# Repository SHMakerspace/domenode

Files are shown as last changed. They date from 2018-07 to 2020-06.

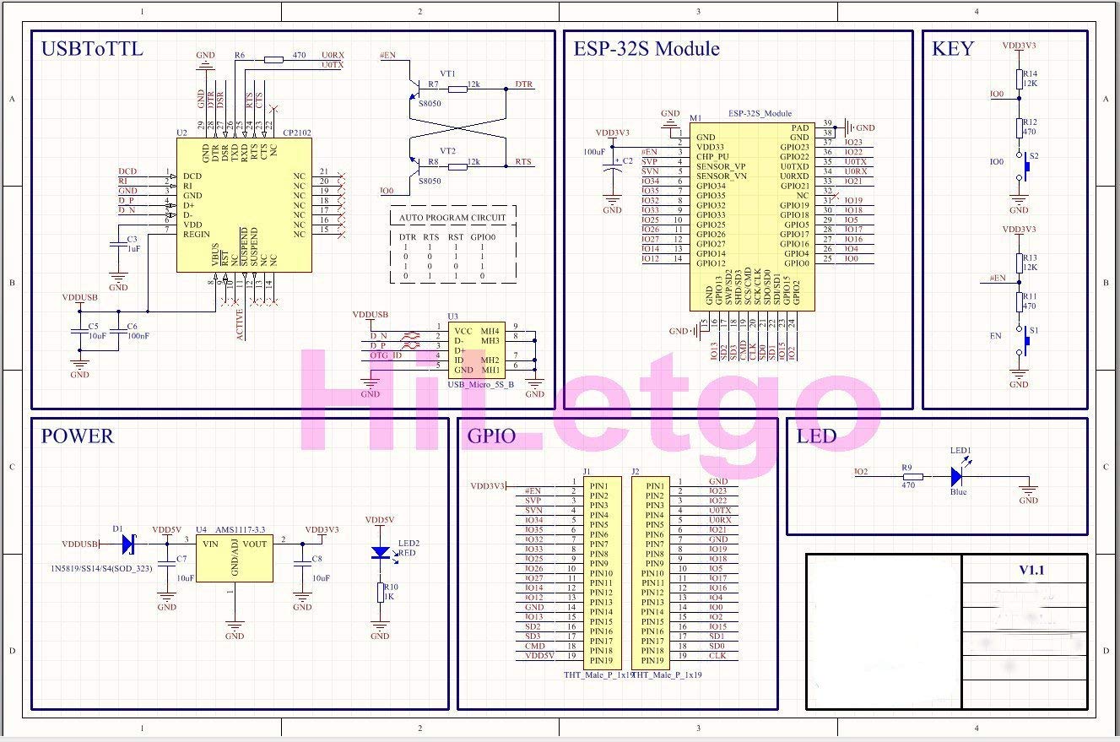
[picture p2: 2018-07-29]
Hardware/Nodes/datasheets/devboard_schematic.jpg

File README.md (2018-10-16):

# domenode
A CAN bus controlled, WiFi enabled network of dome node LEDs with many features

# Features
* :heavy_check_mark: ESP32 microcontroller (WiFi, bluetooth)
  * Pads for both ESP32 standalone module and dev board variants
  * OTA wireless firmware updates
* :heavy_check_mark: SN65HVD230 CAN bus transceiver
* :heavy_check_mark: 2x RJ45 connectors for CAN in and passthrough
* :heavy_check_mark: 5x WS2812/NeoPixel for RGB lighting
* :heavy_check_mark: On-board buck regulator
* :heavy_check_mark: 2x push switches
* :heavy_check_mark: Power and GPIO LED
* :heavy_check_mark: many headers for sensors and attachments (I2C, GPIOs, power etc)
* :red_circle: A shield header for expansion boards (to be added)

# Sensors (all optional and do not need to be populated)
Optional features by means of populating those pads are:
* :question: Outer and inner facing LDRs for ambient/transmitted light sensing
* :question: 2x tactile push switches for on-board input
* :question: Heavier duty power RGB LED shield connector (exposes 24V and R,G,B GPIOs)
* :question: IR Tx/Rx and (hopefully!) a ghetto distance sensor
* :question: Speaker
* :question: Capacitive touch
* :question: Microphone - MAX4466 based breakout board connector (footprints could be added to board, alternative idea is I2S)

# Firmware notes
* CAN bus - http://www.barth-dev.de/can-driver-esp32/
* NeoPixels - https://www.instructables.com/id/ESP32-Bluetooth-Ambience-Light-Controller-With-WS2/
* Microphone -https://www.hackster.io/julianfschroeter/esp32-voice-streamer-52bd7e , https://github.com/MrBuddyCasino/ESP32_Alexa
* Speaker - http://www.xtronical.com/basics/audio/dacs-on-esp32/
* IR sensor - https://github.com/mdhiggins/ESP8266-HTTP-IR-Blaster
* I2C bus - https://randomnerdtutorials.com/esp32-with-bmp180-barometric-sensor/

# BoM and Components

## 1. Basic functionality and programming
* 1x ESP32 module
* 1x SOT-223 3v3 LDO regulator
* 2x 0603 10uF ceramic capacitors (decoupling)
* 2x 100uF tantalum capacitors (decoupling)
* 1x 4 pin ISP header
* 1x 2 pin SW0 flashing header
* 2x 0805 LED (power and blink)
* 2x 0603 resistors for LEDs (470 and 1k)
* 1x 0603 10k resistor EN (very much needed, R10)

## 2. NeoPixels
* 9x WS2812 LEDs
* 1x 0603 470 ohm resistor (R13)
* 9x 0603 100nF ceramic capacitors

## 3. External Power
* 1x MINI-360 buck regulator module (U1)
* 1x 1N5819 protection diode
* 1x 1210 10uF >24v capacitor (C1)
* 2x 0603 10uF ceramic capacitors (C2, C4 decoupling)
* 2x RJ45 connectors

## 4. CAN Bus
* 1x SN65HVD230DR transceiver IC (U6)
* 1x 2 pin CANTERM header
* 1x 0603 120 ohm resistor (R16)
* 1x 0603 10k resistor (R17)
* 1x 0603 100nF capacitor (C14, decoupling)

# Serial Programming
Order is:
Black, Green, White, Red 
(GND), (Rx), (Tx), (5V)

#Flashing Procedure
* 1. Determine COM port with command `mode`
* 2. Open terminal in esp32 python environment
* 3. esptool --chip esp32 -p COM<x> write_flash -z 0x1000 <firmware_bin>

Uploading files

ampy -p COM<x> put <file>

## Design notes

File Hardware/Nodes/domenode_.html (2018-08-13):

## KiBoM PCB Bill of Materials

Source File | D:\P_Projects\domenode\Hardware\Nodes\domenode.sch
BoM Date | 10/08/2018 20:48:50
Schematic Version
Schematic Date
KiCad Version | Eeschema (5.0.0)
Component Groups | 48
Component Count (per PCB) | 80
Fitted Components (per PCB) | 80
Number of PCBs | 1
Total Component Count (for 1 PCBs) | 80

## Component Groups

KiCad Fields (default)

Generated Fields

User Fields

Empty Fields

| Description | Part | References | Value | Footprint | Quantity Per PCB | Datasheet
1 | Unpolarized capacitor | C | C6 C7 C8 C9 C10 C11 C12 C13 C14 C15 | 100nF | C_0603_1608Metric_Pad1.05x0.95mm_HandSolder | 10 | ~
2 | Polarised capacitor | CP | C3 C17 | 100uF | CP_EIA-3528-21_Kemet-B_Pad1.50x2.35mm_HandSolder | 2 | 100uF tantalum cap
3 | Unpolarized capacitor | C | C1 | 10uF | C_1210_3225Metric_Pad1.42x2.65mm_HandSolder | 1 | http://cpc.farnell.com/multicomp/mcca000585/mlcc-1210-y5v-25v-10uf/dp/CA06791?st=10uF%20capacitor
4 | Unpolarized capacitor | C | C2 C4 C5 C16 | 10uF | C_0603_1608Metric_Pad1.05x0.95mm_HandSolder | 4 | ~
5 | Zener Diode | D_Zener | D10 | 1N5819 | D_DO-41_SOD81_P7.62mm_Horizontal | 1 | ~
6 | LED generic | LED | D12 | BLINK | LED_0805_2012Metric_Pad1.15x1.40mm_HandSolder | 1 | ~
7 | Infrared LED , 3mm LED package | IR204A | D13 | IRLED | LED_D3.0mm_IRBlack | 1 | http://www.everlight.com/file/ProductFile/IR204-A.pdf
8 | LED generic | LED | D11 | POWER | LED_0805_2012Metric_Pad1.15x1.40mm_HandSolder | 1 | ~
9 | RGB LED with integrated controller | WS2812B | D1 D2 D3 D4 D5 D6 D7 D8 D9 | WS2812B | LED_WS2812B_PLCC4_5.0x5.0mm_P3.2mm | 9 | https://cdn-shop.adafruit.com/datasheets/WS2812B.pdf
10 | Generic connector, double row, 02x03, odd/even pin numbering scheme (row 1 odd numbers, row 2 even numbers), script generated (kicad-library-utils/schlib/autogen/connector/) | Conn_02x03_Odd_Even | J12 | 24V | PinHeader_2x03_P2.54mm_Vertical | 1 | ~
11 | Generic connector, double row, 02x03, odd/even pin numbering scheme (row 1 odd numbers, row 2 even numbers), script generated (kicad-library-utils/schlib/autogen/connector/) | Conn_02x03_Odd_Even | J5 | 3V3 | PinHeader_2x03_P2.54mm_Vertical | 1 | ~
12 | Generic connector, double row, 02x03, odd/even pin numbering scheme (row 1 odd numbers, row 2 even numbers), script generated (kicad-library-utils/schlib/autogen/connector/) | Conn_02x03_Odd_Even | J10 | 5V | PinHeader_2x03_P2.54mm_Vertical | 1 | ~
13 | Generic connector, single row, 01x02, script generated (kicad-library-utils/schlib/autogen/connector/) | Conn_01x02 | J4 | CANTERM | PinHeader_1x02_P2.54mm_Vertical | 1 | ~
14 | Generic connector, single row, 01x06, script generated (kicad-library-utils/schlib/autogen/connector/) | Conn_01x06 | J13 | CAN_BOARD | PinSocket_1x06_P2.54mm_Vertical | 1 | ~
15 | RJ connector, 8P8C (8 positions 8 connected), RJ31/RJ32/RJ33/RJ34/RJ35/RJ41/RJ45/RJ49/RJ61, Shielded | RJ45_Shielded | J19 | CAN_IN | RJ45_GENERIC | 1 | ~
16 | RJ connector, 8P8C (8 positions 8 connected), RJ31/RJ32/RJ33/RJ34/RJ35/RJ41/RJ45/RJ49/RJ61, Shielded | RJ45_Shielded | J20 | CAN_OUT | RJ45_GENERIC | 1 | ~
17 | Generic connector, single row, 01x04, script generated (kicad-library-utils/schlib/autogen/connector/) | Conn_01x04 | J17 | GROVE/I2C | PinHeader_1x04_P2.54mm_Vertical | 1 | ~
18 | Generic connector, single row, 01x04, script generated (kicad-library-utils/schlib/autogen/connector/) | Conn_01x04 | J18 | ISP | PinHeader_1x04_P2.54mm_Vertical | 1 | ~
19 | Generic connector, single row, 01x03, script generated (kicad-library-utils/schlib/autogen/connector/) | Conn_01x03 | J2 | MIC_HEADER | PinHeader_1x03_P2.54mm_Vertical | 1 | ~
20 | Generic connector, single row, 01x02, script generated (kicad-library-utils/schlib/autogen/connector/) | Conn_01x02 | J1 | MIC_JUMPER | PinHeader_1x02_P2.54mm_Vertical | 1 | ~
21 | Generic connector, single row, 01x03, script generated (kicad-library-utils/schlib/autogen/connector/) | Conn_01x03 | J6 | POWER_TEST | PinHeader_1x03_P2.54mm_Vertical | 1 | ~
22 | Generic connector, single row, 01x05, script generated (kicad-library-utils/schlib/autogen/connector/) | Conn_01x05 | J15 J16 | RGB_SHIELD | PinSocket_1x05_P2.54mm_Vertical | 2 | ~
23 | Generic connector, double row, 02x03, odd/even pin numbering scheme (row 1 odd numbers, row 2 even numbers), script generated (kicad-library-utils/schlib/autogen/connector/) | Conn_02x03_Odd_Even | J9 | SENSOR | PinHeader_2x03_P2.54mm_Vertical | 1 | ~
24 | Generic connector, single row, 01x02, script generated (kicad-library-utils/schlib/autogen/connector/) | Conn_01x02 | J3 | SW0 | PinHeader_1x02_P2.54mm_Vertical | 1 | ~
25 | Generic connector, double row, 02x04, odd/even pin numbering scheme (row 1 odd numbers, row 2 even numbers), script generated (kicad-library-utils/schlib/autogen/connector/) | Conn_02x04_Odd_Even | J21 | SWITCHES | PinHeader_2x04_P2.54mm_Vertical | 1 | ~
26 | Generic connector, double row, 02x03, odd/even pin numbering scheme (row 1 odd numbers, row 2 even numbers), script generated (kicad-library-utils/schlib/autogen/connector/) | Conn_02x03_Odd_Even | J11 | TOUCH | PinHeader_2x03_P2.54mm_Vertical | 1 | ~
27 | light dependent resistor | LDR03 | LDR1 | FLDR | Resistor_LDR_5x4.1_RM3 | 1 | http://www.elektronica-componenten.nl/WebRoot/StoreNL/Shops/61422969/54F1/BA0C/C664/31B9/2173/C0A8/2AB9/2AEF/LDR03IMP.pdf
28 | light dependent resistor | LDR03 | LDR2 | RLDR | Resistor_LDR_5x4.1_RM3 | 1 | http://www.elektronica-componenten.nl/WebRoot/StoreNL/Shops/61422969/54F1/BA0C/C664/31B9/2173/C0A8/2AB9/2AEF/LDR03IMP.pdf
29 | speaker | Speaker | LS1 | Speaker | PinHeader_1x02_P2.54mm_Vertical | 1 | ~
30 | Transistor NPN (general) | Q_NPN_BEC | Q2 | MMBT2222A (2N2222 equiv) | SOT-23_Handsoldering | 1 | ~
31 | Transistor NPN (general) | Q_NPN_BEC | Q1 | MMBT918 (2N706 equiv) | SOT-23_Handsoldering | 1 | ~
32 | Resistor | R | R11 R16 | 100 | R_0805_2012Metric_Pad1.15x1.40mm_HandSolder | 2 | ~
33 | Resistor | R | R1 R4 | 100k | R_0805_2012Metric_Pad1.15x1.40mm_HandSolder | 2 | ~
34 | Resistor | R | R5 R6 R7 R8 R9 R10 R17 | 10k | R_0805_2012Metric_Pad1.15x1.40mm_HandSolder | 7 | ~
35 | Resistor | R | R18 | 120 | R_0805_2012Metric_Pad1.15x1.40mm_HandSolder | 1 | ~
36 | Resistor | R | R12 R15 | 1K | R_0805_2012Metric_Pad1.15x1.40mm_HandSolder | 2 | ~
37 | Resistor | R | R13 R14 | 470 | R_0805_2012Metric_Pad1.15x1.40mm_HandSolder | 2 | ~
38 | Resistor | R | R2 | 4K | R_0805_2012Metric_Pad1.15x1.40mm_HandSolder | 1 | ~
39 | Resistor | R | R3 | 5K | R_0805_2012Metric_Pad1.15x1.40mm_HandSolder | 1 | ~
40 | Push button switch, generic, two pins | SW_Push | SW4 | BOOT | SW_SPST_B3U-1000P | 1
41 | Push button switch, generic, two pins | SW_Push | SW3 | RESET | SW_SPST_B3U-1000P | 1
42 | Push button switch, generic, two pins | SW_Push | SW1 | SW1 | SW_SPST_B3U-1000P | 1
43 | Push button switch, generic, two pins | SW_Push | SW2 | SW2 | SW_SPST_B3U-1000P | 1
44 | 1A Low Dropout regulator, positive, 1.5V fixed output, SOT-223 | AMS1117-3.3 | U2 | AMS1117-3.3 | SOT-223-3_TabPin2 | 1 | http://www.advanced-monolithic.com/pdf/ds1117.pdf
45 | | ESP32-WROOM | U3 | ESP32-WROOM | ESP32-WROOM | 1
46 | | MINI-360 | U1 | MINI-360 | MINI-360 | 1
47 | CAN Bus Transceivers, 3.3V, 1Mbps, Low-Power capabilities, SOIC | SN65HVD230 | U6 | SN65HVD230 | SOIC-8_3.9x4.9mm_P1.27mm | 1 | http://www.ti.com/lit/ds/symlink/sn65hvd230.pdf
48 | IR Receiver Modules for Data Transmission | TSDP341xx | U5 | TSDP341xx | Vishay_MOLD-3Pin | 1 | http://www.vishay.com/docs/82667/tsdp341.pdf

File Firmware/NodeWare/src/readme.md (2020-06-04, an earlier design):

# DomeNode Firmware
The firmware for the DomeNodes is written in Arduino for the ESP32 microcontroller platform

## Dependencies
The required dependancies are included with this repository as submodules, except the ESP32 Arduino core toolchain which has to be installed manually.
* [Arduino core for ESP32 WiFi chip](https://github.com/espressif/arduino-esp32) - install via Arduino IDE boards manager
* [Arduino CAN](https://github.com/sandeepmistry/arduino-CAN) - included as submodule
* [NeoPixelBus](https://github.com/Makuna/NeoPixelBus) - included as submodule

## Compiling
To compile the firmware correctly for the DomeNode, please ensure your Arduino IDE has the following parameters set in the 'Tools' menu;
* Board: ESP32 Dev Module
* Flash mode: QIO
* Flash frequency: 40MHz
* Flash size: 4MB (32Mb)
* PSRAM: Disabled
* Partition scheme: Minimal SPIFFS (Large apps with OTA)
* Upload speed: 921600
* Core debug level: None

## Node IDs
To assign an ID to a node, simply set the `node_id` to your chosen ID and it will be persistantly stored. You only need this variable set once, you can remove it from future firmware uploads it it'll retrive the last set ID from flash memory.

## OTA updates
To update via OTA, first flash the firmware over serial, ensuring that you have changed the WiFi credentials to the same network your machine running the Arduino IDE is connected to.
When the DomeNode connects to your network, navigate to the 'Port' option under the 'Tools' in the Arduino IDE. You should your DomeNode appear under the serial ports.

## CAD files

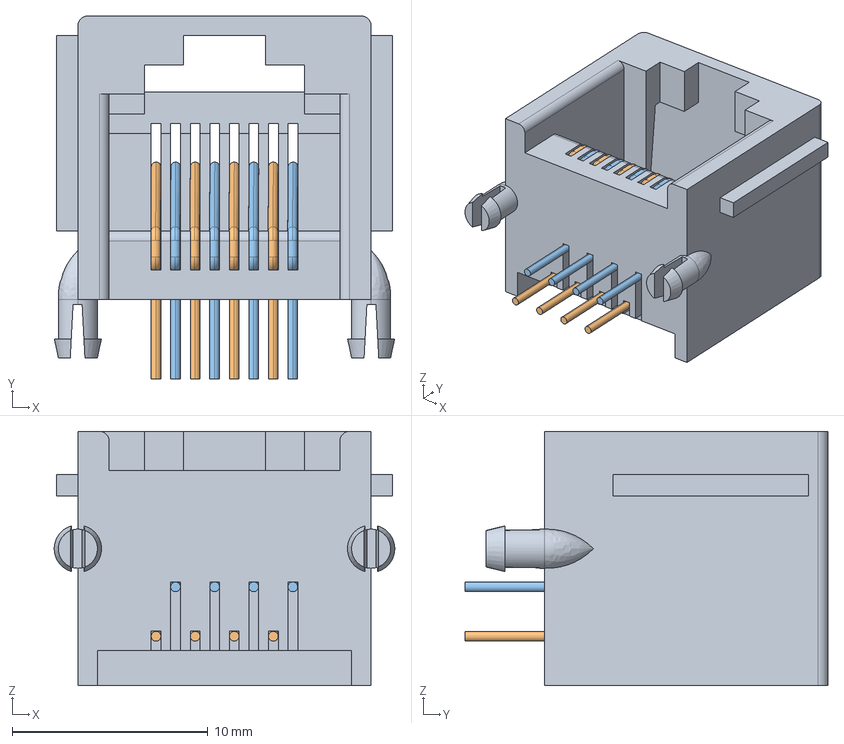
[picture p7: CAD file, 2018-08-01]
Hardware/Nodes/kicad_libraries/3dmodels/rj45_socket_asm.stp
17.4 x 18.6 x 13.0 mm
PIN x 4
PIN2 x 4

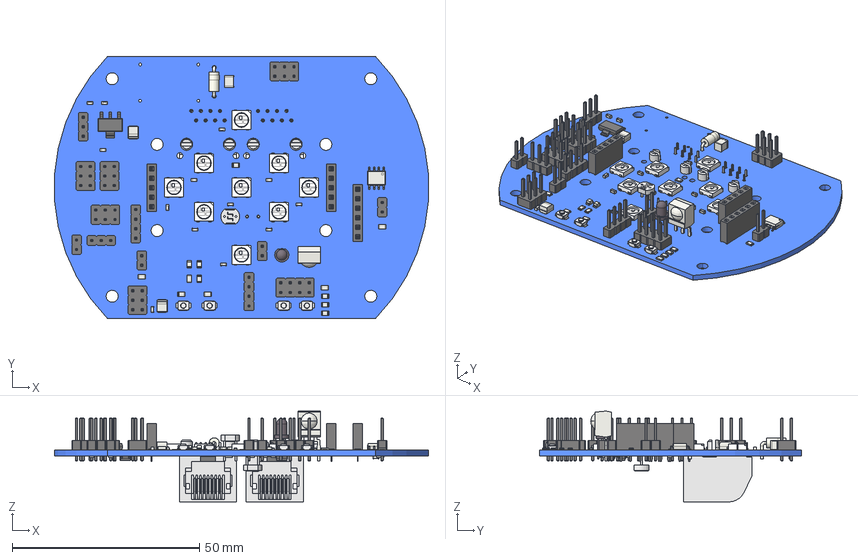
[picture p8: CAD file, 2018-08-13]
Hardware/Nodes/domenode.FCStd
99.8 x 70.0 x 24.2 mm
Pcb
SOT_223_
risk1E78E08Bni4a_
D_DO-41_SOD81_P7.62mm_Horizontal_
LED_D3.0mm_IRBlack_
risk1E78E08Bni4a_001
risk1E78E08Bni4a_002
risk1E78E08Bni4a_003
R_LDR_5.0x4.1mm_P3mm_Vertical_
risk1E78E08Bni4a_004
risk1E78E08Bni4a_005
risk1E78E08Bni4a_006
risk1E78E08Bni4a_007
risk1E78E08Bni4a_008
PinHeader_2x03_P254mm_Vertical_
PinHeader_2x03_P254mm_Vertical_001
PinHeader_2x04_P254mm_Vertical_
SOIC_8_39x49mm_P127mm_
C_0603_1608Metric_
C_0603_1608Metric_001
C_0603_1608Metric_002
C_0603_1608Metric_003
C_0603_1608Metric_004
C_0603_1608Metric_005
C_0603_1608Metric_006
C_0603_1608Metric_007
C_0603_1608Metric_008
C_0603_1608Metric_009
C_0603_1608Metric_010
LED_0805_2012Metric_
LED_0805_2012Metric_001
PinHeader_1x02_P254mm_Vertical_
PinHeader_1x03_P254mm_Vertical_
PinHeader_1x02_P254mm_Vertical_001
PinSocket_1x06_P254mm_Vertical_
PinSocket_1x05_P254mm_Vertical_
PinSocket_1x05_P254mm_Vertical_001
PinHeader_1x04_P254mm_Vertical_
PinHeader_1x04_P254mm_Vertical_001
Vishay_MOLD-3pin_
CP_EIA_3528_21_Kemet_B_
PinHeader_1x02_P254mm_Vertical_002
PinHeader_2x03_P254mm_Vertical_002
PinHeader_2x03_P254mm_Vertical_003
PinHeader_2x03_P254mm_Vertical_004
R_0805_2012Metric_004
R_0805_2012Metric_005
R_0805_2012Metric_006
R_0805_2012Metric_007
R_0805_2012Metric_008
R_0805_2012Metric_009
R_0805_2012Metric_010
R_0805_2012Metric_011
R_0805_2012Metric_012
R_0805_2012Metric_013
R_0805_2012Metric_017
C_0603_1608Metric_012
SW_SPST_B3U-1000P_
SW_SPST_B3U-1000P_001
SW_SPST_B3U-1000P_002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

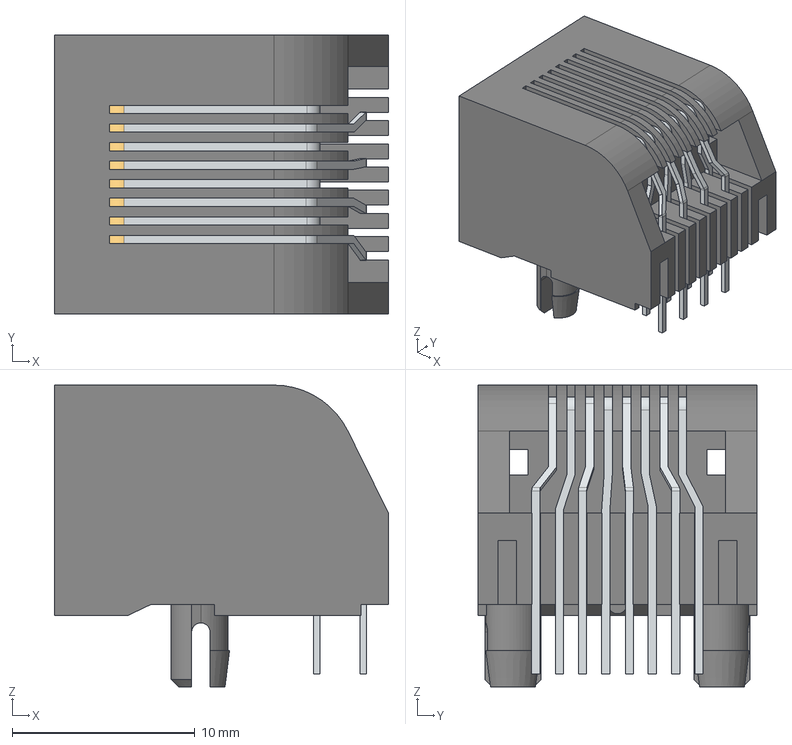
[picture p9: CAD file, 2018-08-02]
Hardware/Nodes/kicad_libraries/3dmodels/wurth_615008143721 (rev1).stp
18.3 x 15.2 x 16.5 mm
pin1
pin2
pin3
pin5
pin7
pin6
pin4
pin8
housing

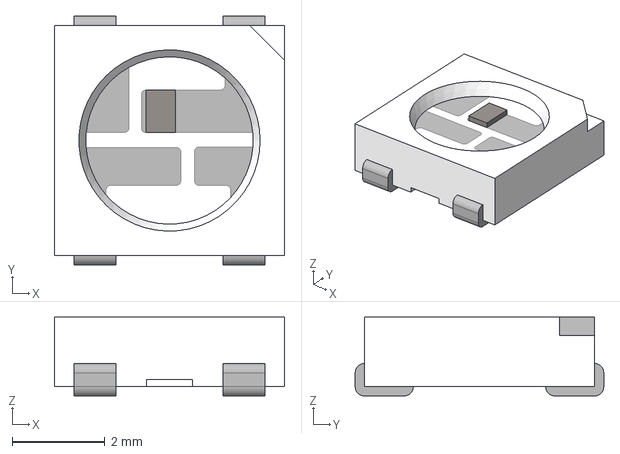
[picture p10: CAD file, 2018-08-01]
Hardware/Nodes/kicad_libraries/3dmodels/WS2812_RGB_LED_updated.stp
4.95 x 5.35 x 1.70 mm

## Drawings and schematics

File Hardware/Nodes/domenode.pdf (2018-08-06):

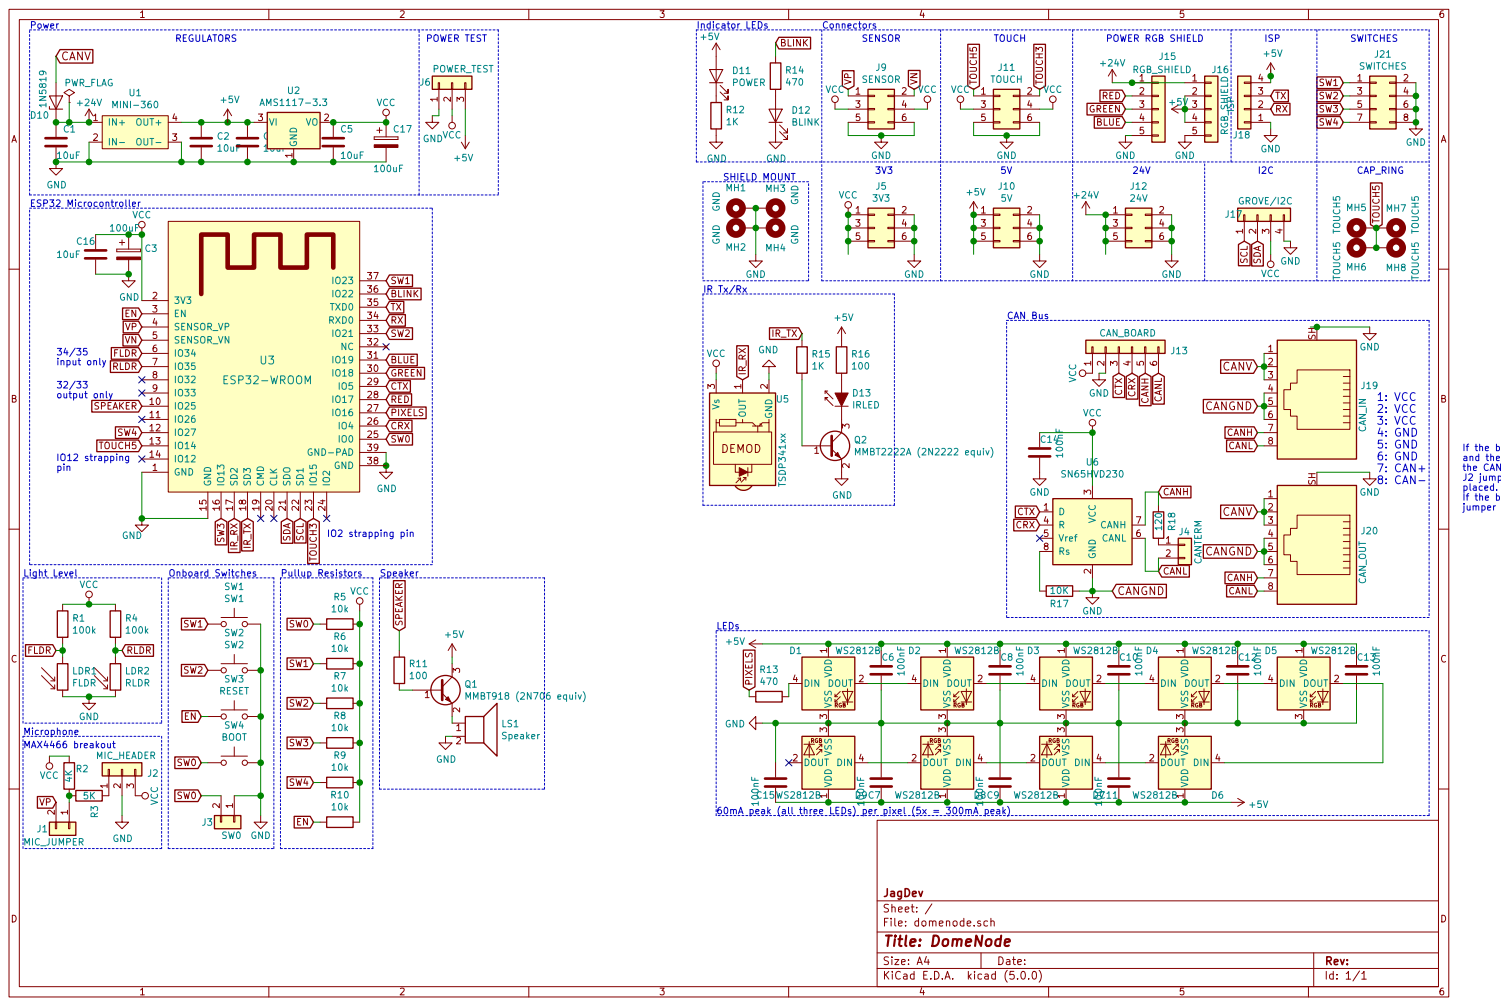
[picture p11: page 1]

J13 CAN_BOARD CTX CRX CANH CANL GND VCC

CANL CANL CANH CANL CANH

If the board is the first and the last node of
the CAN network, then
J2 jumper should be
placed.
If the board is a node in the middle,

jumper should be removed. 1

60mA peak (all three LEDs) per pixel (5x = 300mA peak) R1
100k GND

File: domenode.sch Sheet: / JagDev

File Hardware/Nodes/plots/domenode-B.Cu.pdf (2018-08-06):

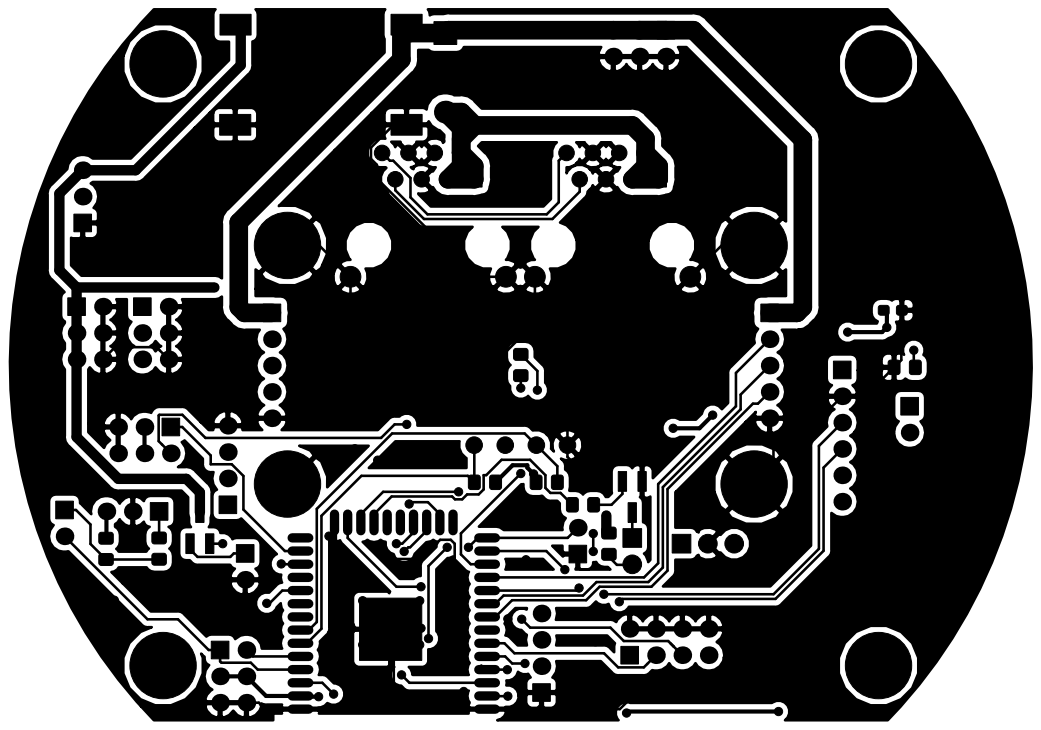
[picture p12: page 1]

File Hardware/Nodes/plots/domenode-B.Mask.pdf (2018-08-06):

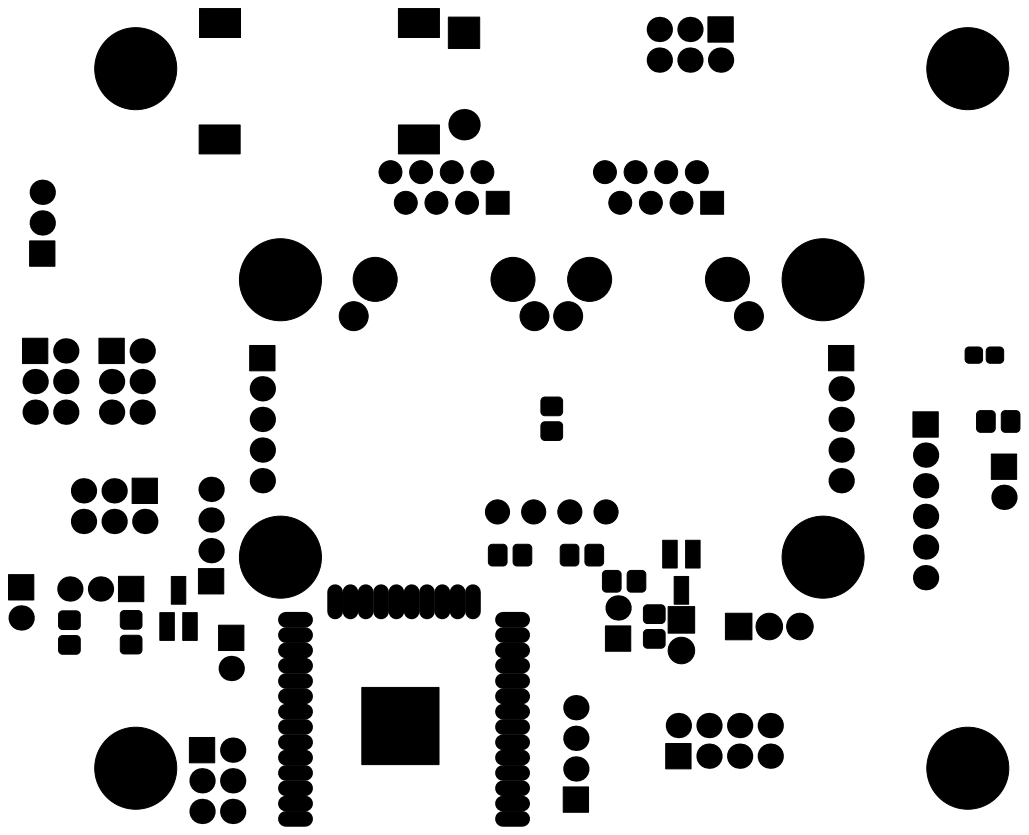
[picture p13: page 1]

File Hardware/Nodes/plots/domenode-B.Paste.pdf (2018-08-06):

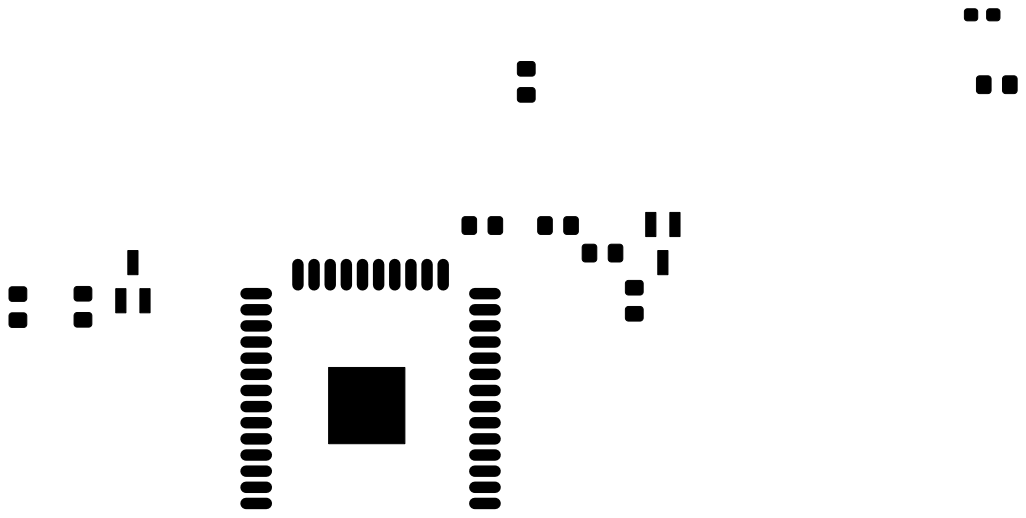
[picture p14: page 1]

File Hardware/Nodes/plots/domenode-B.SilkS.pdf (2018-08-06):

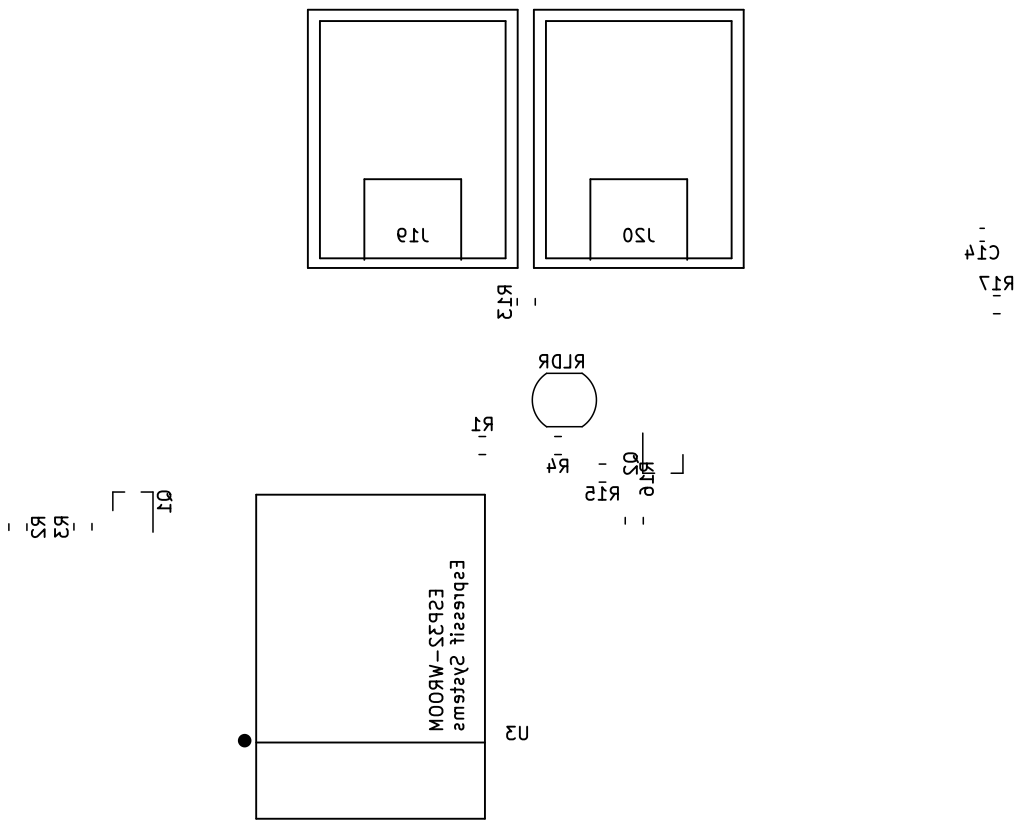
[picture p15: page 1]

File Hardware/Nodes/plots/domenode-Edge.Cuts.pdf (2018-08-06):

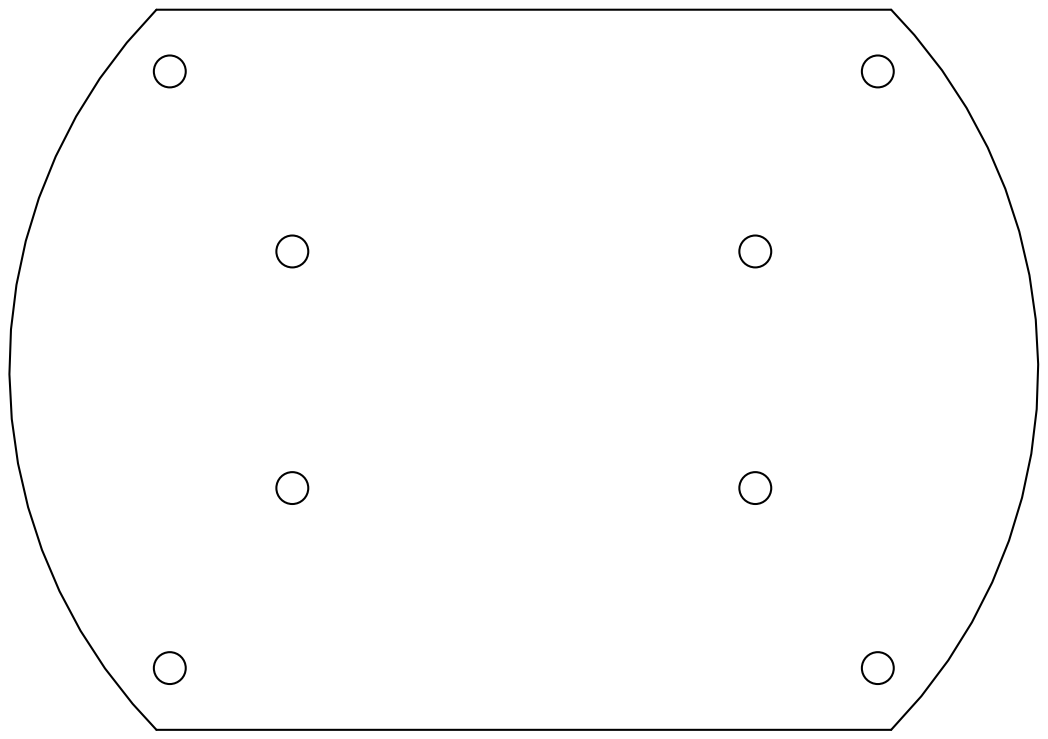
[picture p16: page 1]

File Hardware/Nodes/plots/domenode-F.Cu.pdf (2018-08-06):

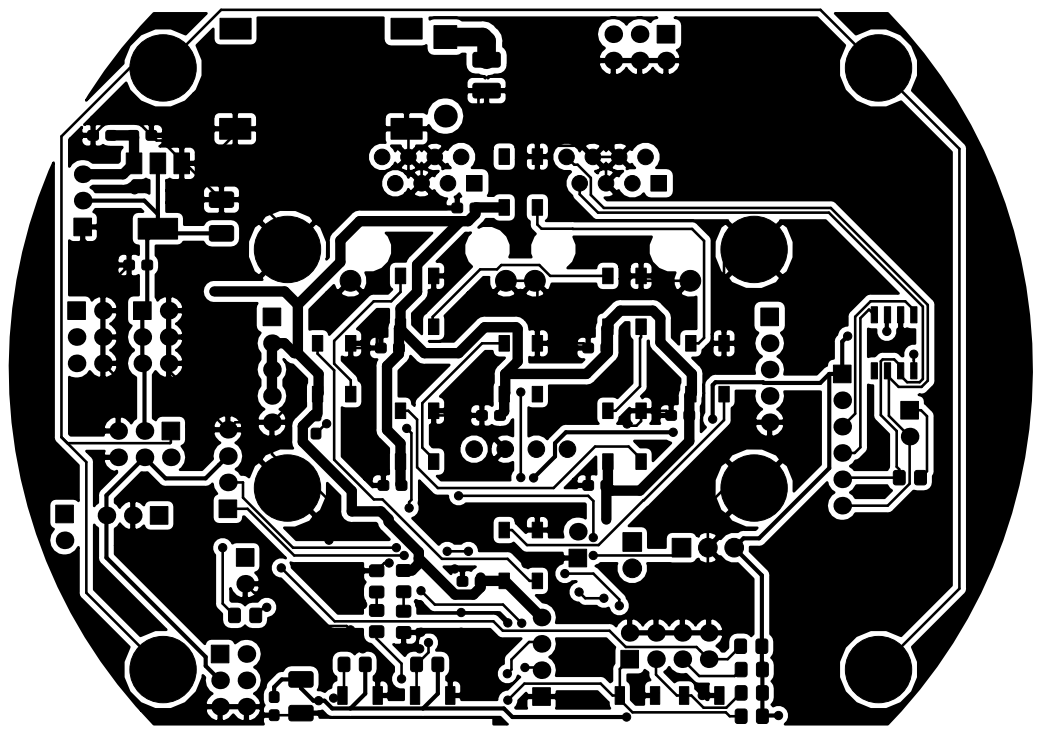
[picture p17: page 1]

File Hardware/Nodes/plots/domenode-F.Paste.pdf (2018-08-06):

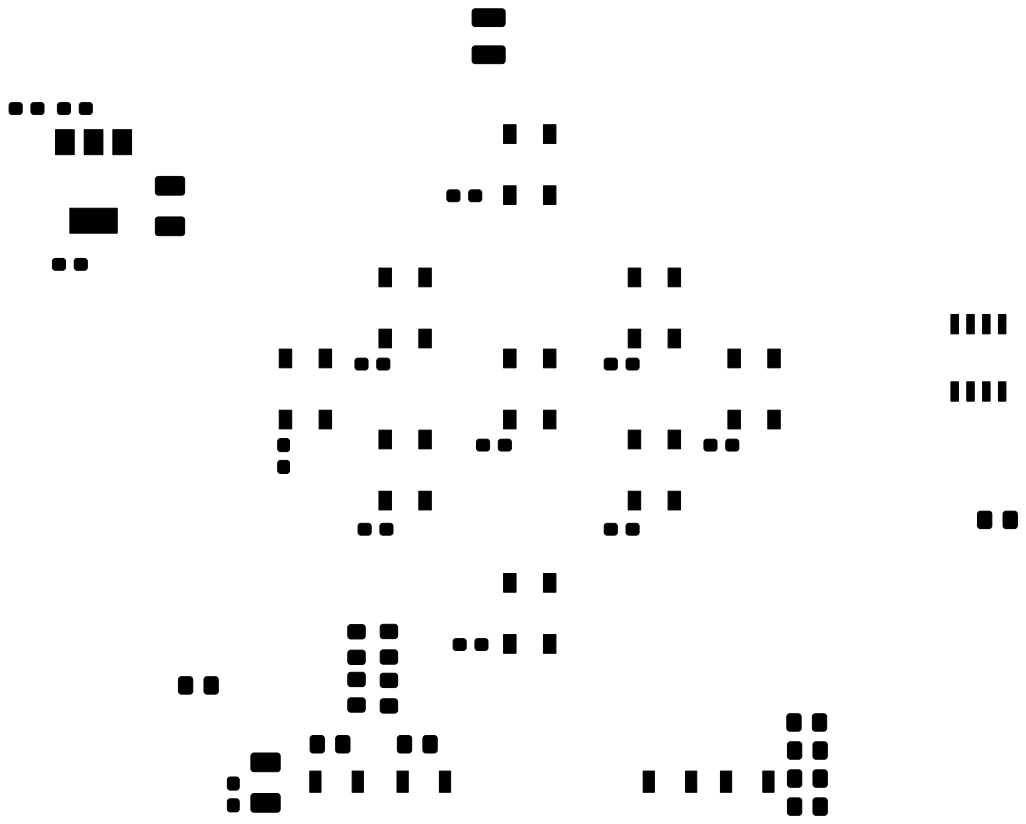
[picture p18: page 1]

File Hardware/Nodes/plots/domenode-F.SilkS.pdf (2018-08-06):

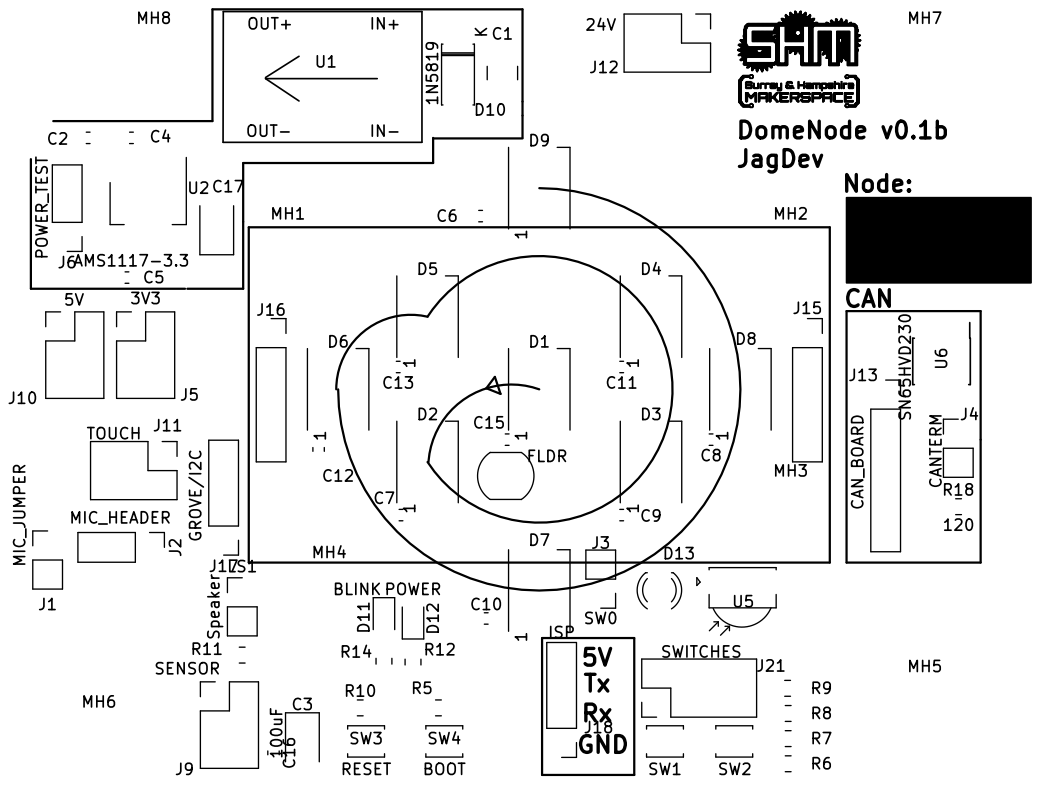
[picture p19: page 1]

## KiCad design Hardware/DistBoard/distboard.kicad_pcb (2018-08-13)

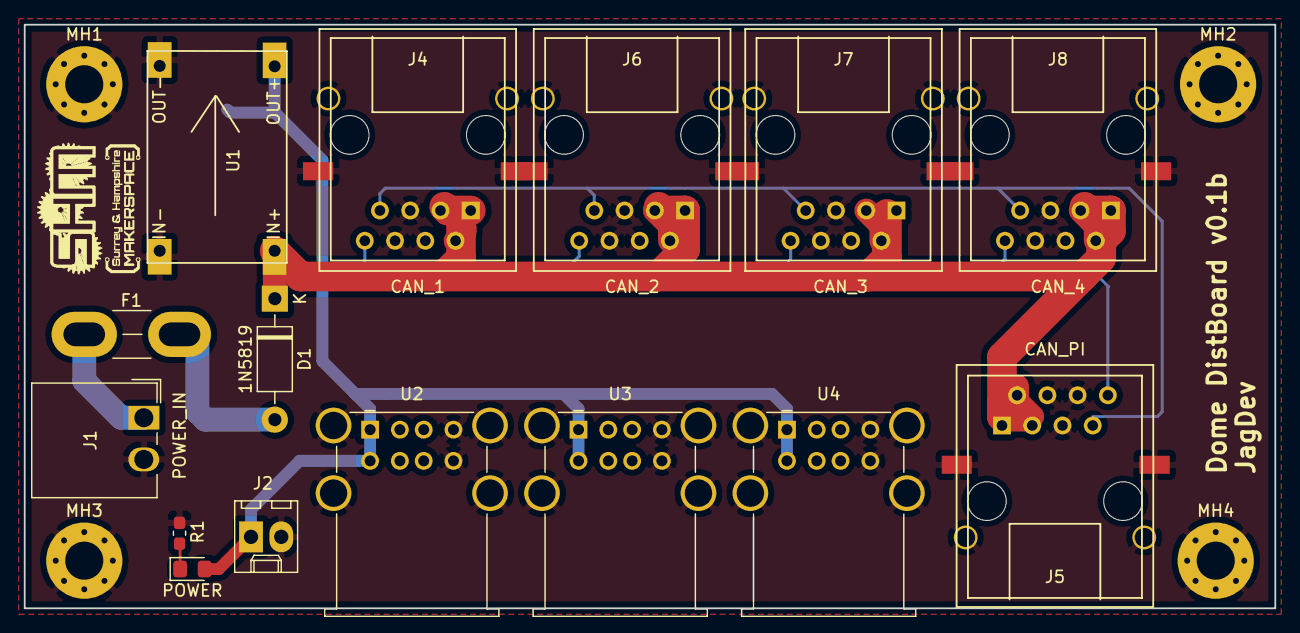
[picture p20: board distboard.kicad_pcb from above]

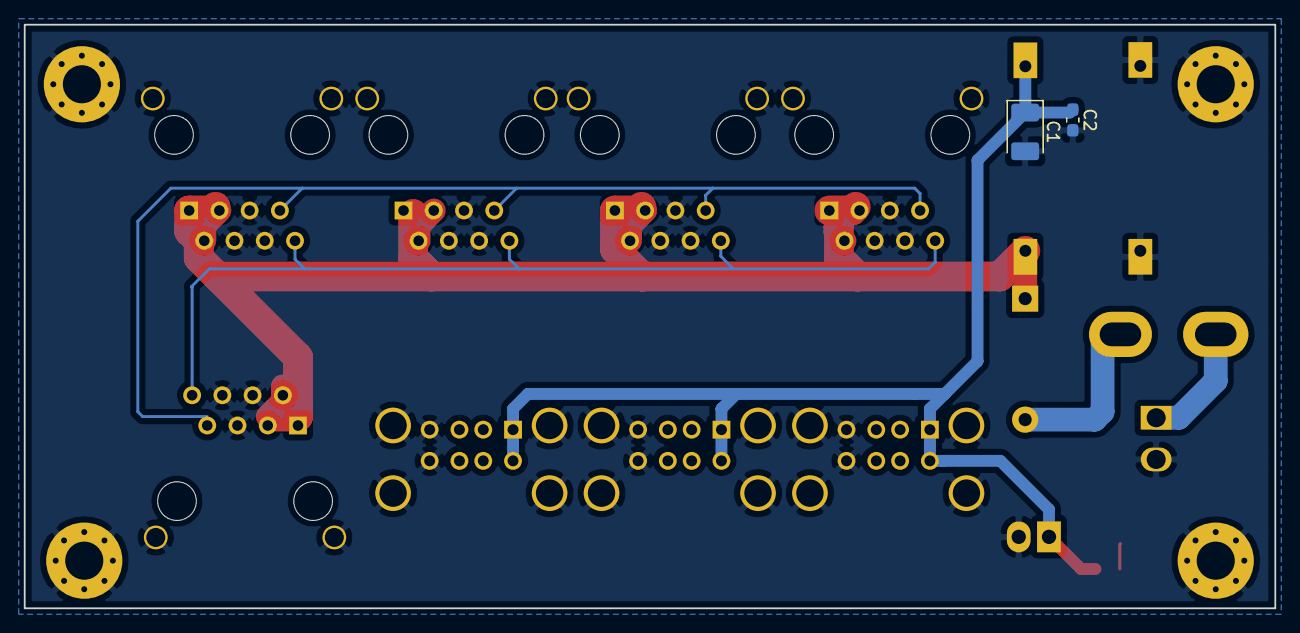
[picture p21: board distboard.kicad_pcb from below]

Board: 2 copper layers, 105.0 x 49.0 mm, 22 parts (2 on the bottom side), 8 nets.

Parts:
C1: 100uF; CP_EIA-3528-21_Kemet-B_Pad1.50x2.35mm_HandSolder
C2: 10uF; C_0603_1608Metric_Pad1.05x0.95mm_HandSolder
D1: 1N5819; D_DO-41_SOD81_P10.16mm_Horizontal
D2: POWER; LED_0805_2012Metric_Pad1.15x1.40mm_HandSolder
F1: Fuse; BladeFuse-Mini
J1: POWER_IN; Wago_734-162_1x02_P3.50mm_Horizontal
J2: FAN_HEADER; Molex_KK-6410-02_02x2.54mm_Straight
J4: CAN_1; RJ45_GENERIC
J5: CAN_PI; RJ45_GENERIC
J6: CAN_2; RJ45_GENERIC
J7: CAN_3; RJ45_GENERIC
J8: CAN_4; RJ45_GENERIC
MH1, MH2, MH3, MH4: MountingHole_Pad; MountingHole_3.2mm_M3_Pad_Via
R1: 1K; R_0603_1608Metric_Pad1.05x0.95mm_HandSolder
U1: MINI-360
U2, U3, U4: double_usb; USB_A_Wuerth_61400826021_Horizontal_Stacked
shm_logo_small: shm_logo_small

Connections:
+5V: C1.1, C2.1, D2.2, J2.1, U1.4, U2.1, U2.5, U3.1, U3.5, U4.1, U4.5
CANGND: C1.2, C2.2, J1.2, J2.2, J4.4, J4.5, J4.6, J4.SH, J5.4, J5.5, J5.6, J5.SH, J6.4, J6.5, J6.6, J6.SH, J7.4, J7.5, J7.6, J7.SH, J8.4, J8.5, J8.6, J8.SH, MH1.1, MH2.1, MH3.1, MH4.1, R1.2, U1.2, U1.3, U2.4, U2.8, U2.9, U3.4, U3.8, U3.9, U4.4, U4.8, U4.9
CANH: J4.7, J5.7, J6.7, J7.7, J8.7
CANL: J4.8, J5.8, J6.8, J7.8, J8.8
CANV: D1.1, J4.1, J4.2, J4.3, J5.1, J5.2, J5.3, J6.1, J6.2, J6.3, J7.1, J7.2, J7.3, J8.1, J8.2, J8.3, U1.1
unnamed: D1.2, F1.2
unnamed: D2.1, R1.1
unnamed: F1.1, J1.1

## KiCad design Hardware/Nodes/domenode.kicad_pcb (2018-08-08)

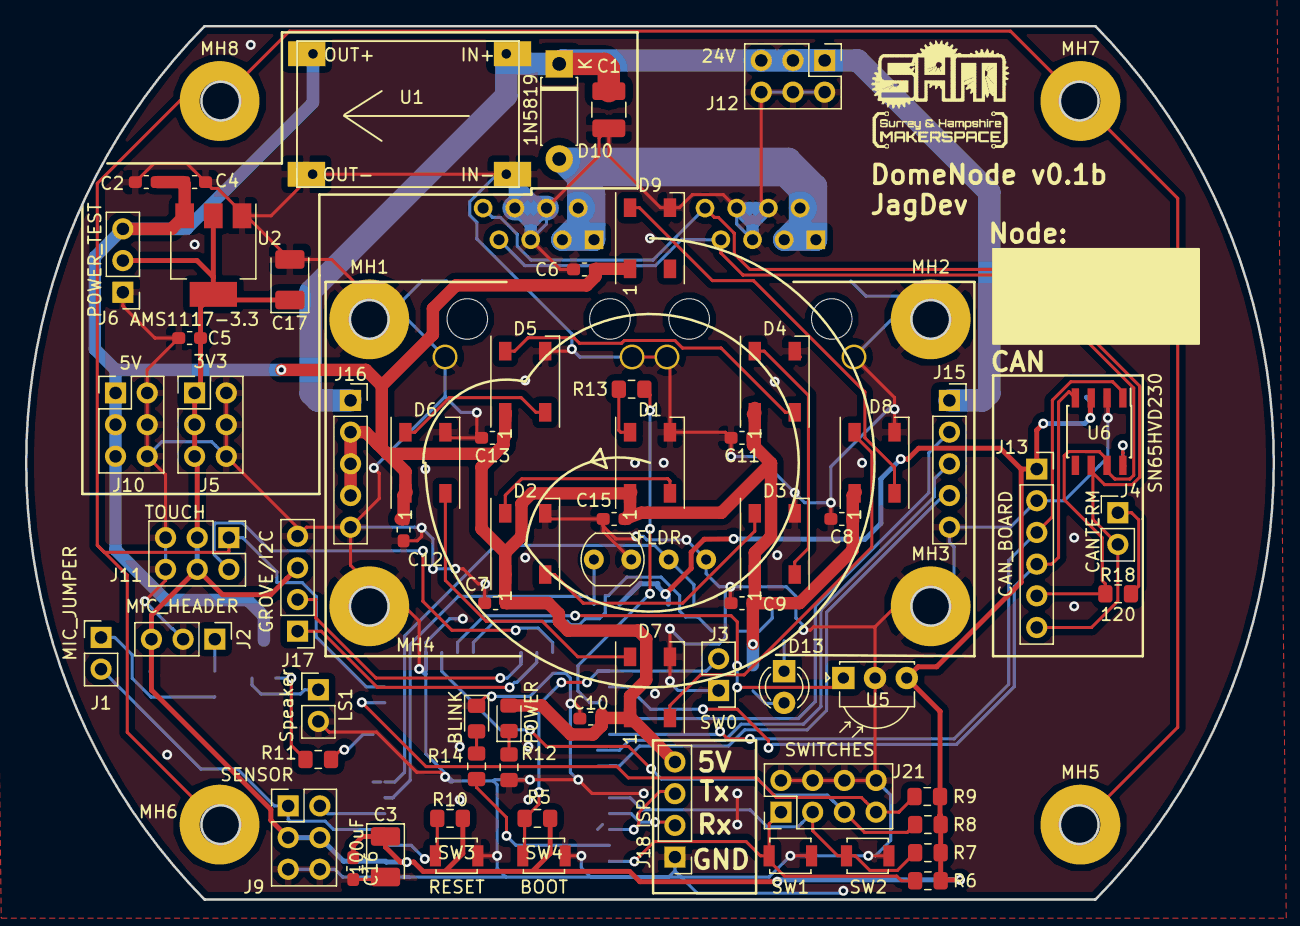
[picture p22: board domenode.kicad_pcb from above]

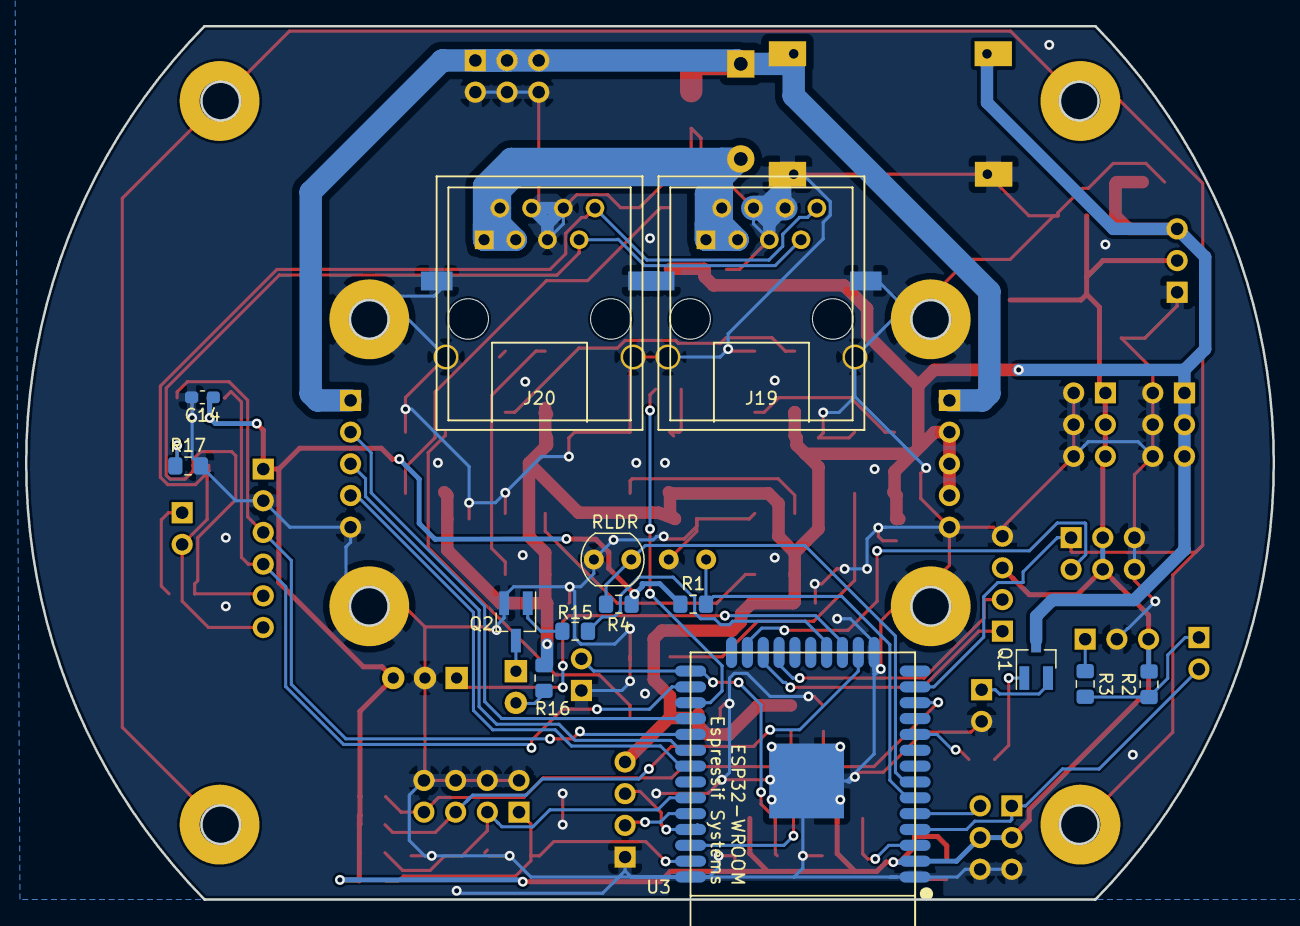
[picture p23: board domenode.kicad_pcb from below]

Board: 2 copper layers, 100.0 x 70.0 mm, 89 parts (14 on the bottom side), 53 nets.

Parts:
C1: 10uF; C_1210_3225Metric_Pad1.42x2.65mm_HandSolder
C2, C4, C5, C16: 10uF; C_0603_1608Metric_Pad1.05x0.95mm_HandSolder
C3, C17: 100uF; CP_EIA-3528-21_Kemet-B_Pad1.50x2.35mm_HandSolder
C6, C7, C8, C9, C10, C11, C12, C13, C14, C15: 100nF; C_0603_1608Metric_Pad1.05x0.95mm_HandSolder
D1, D2, D3, D4, D5, D6, D7, D8, D9: WS2812B; LED_WS2812B_PLCC4_5.0x5.0mm_P3.2mm
D10: 1N5819; D_DO-41_SOD81_P7.62mm_Horizontal
D11: POWER; LED_0805_2012Metric_Pad1.15x1.40mm_HandSolder
D12: BLINK; LED_0805_2012Metric_Pad1.15x1.40mm_HandSolder
D13: IRLED; LED_D3.0mm_IRBlack
J1: MIC_JUMPER; PinHeader_1x02_P2.54mm_Vertical
J2: MIC_HEADER; PinHeader_1x03_P2.54mm_Vertical
J3: SW0; PinHeader_1x02_P2.54mm_Vertical
J4: CANTERM; PinHeader_1x02_P2.54mm_Vertical
J5: 3V3; PinHeader_2x03_P2.54mm_Vertical
J6: POWER_TEST; PinHeader_1x03_P2.54mm_Vertical
J9: SENSOR; PinHeader_2x03_P2.54mm_Vertical
J10: 5V; PinHeader_2x03_P2.54mm_Vertical
J11: TOUCH; PinHeader_2x03_P2.54mm_Vertical
J12: 24V; PinHeader_2x03_P2.54mm_Vertical
J13: CAN_BOARD; PinSocket_1x06_P2.54mm_Vertical
J15, J16: RGB_SHIELD; PinSocket_1x05_P2.54mm_Vertical
J17: GROVE/I2C; PinHeader_1x04_P2.54mm_Vertical
J18: ISP; PinHeader_1x04_P2.54mm_Vertical
J19: CAN_IN; RJ45_GENERIC
J20: CAN_OUT; RJ45_GENERIC
J21: SWITCHES; PinHeader_2x04_P2.54mm_Vertical
LDR1: FLDR; Resistor_LDR_5x4.1_RM3
LDR2: RLDR; Resistor_LDR_5x4.1_RM3
LS1: Speaker; PinHeader_1x02_P2.54mm_Vertical
MH1, MH2, MH3, MH4: GND; MountingHole_3.2mm_M3_Pad
MH5, MH6, MH7, MH8: TOUCH5; MountingHole_3.2mm_M3_Pad
Q1: MMBT918 (2N706 equiv); SOT-23_Handsoldering
Q2: MMBT2222A (2N2222 equiv); SOT-23_Handsoldering
R1, R4: 100k; R_0805_2012Metric_Pad1.15x1.40mm_HandSolder
R2: 4K; R_0805_2012Metric_Pad1.15x1.40mm_HandSolder
R3: 5K; R_0805_2012Metric_Pad1.15x1.40mm_HandSolder
R5, R6, R7, R8, R9, R10: 10k; R_0805_2012Metric_Pad1.15x1.40mm_HandSolder
R11, R16: 100; R_0805_2012Metric_Pad1.15x1.40mm_HandSolder
R12, R15: 1K; R_0805_2012Metric_Pad1.15x1.40mm_HandSolder
R13, R14: 470; R_0805_2012Metric_Pad1.15x1.40mm_HandSolder
R17: 10K; R_0805_2012Metric_Pad1.15x1.40mm_HandSolder
R18: 120; R_0805_2012Metric_Pad1.15x1.40mm_HandSolder
SW1: SW1; SW_SPST_B3U-1000P
SW2: SW2; SW_SPST_B3U-1000P
SW3: RESET; SW_SPST_B3U-1000P
SW4: BOOT; SW_SPST_B3U-1000P
U1: MINI-360
U2: AMS1117-3.3; SOT-223-3_TabPin2
U3: ESP32-WROOM
U5: TSDP341xx; Vishay_MOLD-3Pin
U6: SN65HVD230; SOIC-8_3.9x4.9mm_P1.27mm
shm_logo_small: shm_logo_small

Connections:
+5V: C2.1, C4.1, C6.1, C7.1, C8.1, C9.1, C10.1, C11.1, C12.1, C13.1, C15.1, D1.1, D2.1, D3.1, D4.1, D5.1, D6.1, D7.1, D8.1, D9.1, D11.2, J6.3, J10.1, J10.3, J10.5, J16.2, J16.3, J16.4, J18.4, Q1.3, R16.1, U1.4, U2.3
+24V: C1.1, D10.1, J12.1, J12.3, J12.5, J15.1, J16.1, U1.1
BLINK: R14.1, U3.36
BLUE: J15.4, U3.31
CANGND: C1.2, C2.2, C3.2, C4.2, C5.2, C6.2, C7.2, C8.2, C9.2, C10.2, C11.2, C12.2, C13.2, C14.2, C15.2, C16.2, C17.2, D1.3, D2.3, D3.3, D4.3, D5.3, D6.3, D7.3, D8.3, D9.3, D12.1, J2.2, J3.1, J5.2, J5.4, J5.6, J6.1, J9.5, J9.6, J10.2, J10.4, J10.6, J11.5, J11.6, J12.2, J12.4, J12.6, J13.2, J15.5, J16.5, J17.4, J18.1, J19.4, J19.5, J19.6, J19.SH, J20.4, J20.5, J20.6, J20.SH, J21.2, J21.4, J21.6, J21.8, LDR1.2, LDR2.2, LS1.2, MH1.1, MH2.1, MH3.1, MH4.1, Q2.2, R12.2, R17.2, SW1.2, SW2.2, SW3.2, SW4.2, U1.2, U1.3, U2.1, U3.1, U3.15, U3.38, U3.39, U5.2, U6.2
CANH: J13.5, J19.7, J20.7, R18.1, U6.7
CANL: J4.2, J13.6, J19.8, J20.8, U6.6
CANV: D10.2, J19.1, J19.2, J19.3, J20.1, J20.2, J20.3
CRX: J13.4, U3.26, U6.4
CTX: J13.3, U3.29, U6.1
EN: R10.2, SW3.1, U3.3
FLDR: LDR1.1, R1.2, U3.6
GREEN: J15.3, U3.30
IR_RX: U3.17, U5.1
IR_TX: R15.1, U3.18
unnamed: D1.2, D2.4
unnamed: D1.4, R13.1
unnamed: D2.2, D3.4
unnamed: D3.2, D4.4
unnamed: D4.2, D5.4
unnamed: D5.2, D6.4
unnamed: D6.2, D7.4
unnamed: D7.2, D8.4
unnamed: D8.2, D9.4
unnamed: D11.1, R12.1
unnamed: D12.2, R14.2
unnamed: D13.1, Q2.3
unnamed: D13.2, R16.2
unnamed: J1.1, R2.1, R3.2
unnamed: J2.1, R3.1
unnamed: J4.1, R18.2
unnamed: LS1.1, Q1.2
unnamed: Q1.1, R11.1
unnamed: Q2.1, R15.2
unnamed: R17.1, U6.8
PIXELS: R13.2, U3.27
RED: J15.2, U3.28
RLDR: LDR2.1, R4.2, U3.7
RX: J18.2, U3.34
SCL: J17.1, U3.22
SDA: J17.2, U3.21
SPEAKER: R11.2, U3.10
SW0: J3.2, R5.2, SW4.1, U3.25
SW1: J21.1, R6.2, SW1.1, U3.37
SW2: J21.3, R7.2, SW2.1, U3.33
SW3: J21.5, R8.2, U3.16
SW4: J21.7, R9.2, U3.12
TOUCH3: J11.2, U3.23
TOUCH5: J11.1, MH5.1, MH6.1, MH7.1, MH8.1, U3.13
TX: J18.3, U3.35
VCC: C3.1, C5.1, C14.1, C16.1, C17.1, J2.3, J5.1, J5.3, J5.5, J6.2, J9.3, J9.4, J11.3, J11.4, J13.1, J17.3, R1.1, R2.2, R4.1, R5.1, R6.1, R7.1, R8.1, R9.1, R10.1, U2.2, U3.2, U5.3, U6.3
VN: J9.2, U3.5
VP: J1.2, J9.1, U3.4

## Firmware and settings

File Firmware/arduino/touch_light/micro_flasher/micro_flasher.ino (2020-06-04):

// ArduinoISP
// Copyright (c) 2008-2011 Randall Bohn
// If you require a license, see
//     http://www.opensource.org/licenses/bsd-license.php
//
// This sketch turns the Arduino into a AVRISP
// using the following arduino pins:
//
// Pin 10 is used to reset the target microcontroller.
//
// By default, the hardware SPI pins MISO, MOSI and SCK pins are used
// to communicate with the target. On all Arduinos, these pins can be found
// on the ICSP/SPI header:
//
//               MISO °. . 5V (!) Avoid this pin on Due, Zero...
//               SCK   . . MOSI
//                     . . GND
//
// On some Arduinos (Uno,...), pins MOSI, MISO and SCK are the same pins
// as digital pin 11, 12 and 13, respectively. That is why many tutorials
// instruct you to hook up the target to these pins. If you find this wiring
// more practical, have a define USE_OLD_STYLE_WIRING. This will work even
// even when not using an Uno. (On an Uno this is not needed).
//
// Alternatively you can use any other digital pin by configuring software ('BitBanged')
// SPI and having appropriate defines for PIN_MOSI, PIN_MISO and PIN_SCK.
// 
// IMPORTANT: When using an Arduino that is not 5V tolerant (Due, Zero, ...)
// as the programmer, make sure to not expose any of the programmer's pins to 5V.
// A simple way to accomplish this is to power the complete system (programmer
// and target) at 3V3.
//
// Put an LED (with resistor) on the following pins:
// 9: Heartbeat   - shows the programmer is running
// 8: Error       - Lights up if something goes wrong (use red if that makes sense)
// 7: Programming - In communication with the slave
//

#include "Arduino.h"
#undef SERIAL


#define PROG_FLICKER true

// Configure SPI clock (in Hz).
// E.g. for an attiny @128 kHz: the datasheet states that both the high
// and low spi clock pulse must be > 2 cpu cycles, so take 3 cycles i.e.
// divide target f_cpu by 6:
//     #define SPI_CLOCK            (128000/6)
//
// A clock slow enough for an attiny85 @ 1MHz, is a reasonable default:

#define SPI_CLOCK 		(1000000/6)


// Select hardware or software SPI, depending on SPI clock.
// Currently only for AVR, for other archs (Due, Zero,...),
// hardware SPI is probably too fast anyway.

#if defined(ARDUINO_ARCH_AVR)

#if SPI_CLOCK > (F_CPU / 128)
#define USE_HARDWARE_SPI
#endif

#endif

// Configure which pins to use:

// The standard pin configuration.
#ifndef ARDUINO_HOODLOADER2 

#define RESET     10 // Use pin 10 to reset the target rather than SS
#define LED_HB    9
#define LED_ERR   8
#define LED_PMODE 7

// Uncomment following line to use the old Uno style wiring
// (using pin 11, 12 and 13 instead of the SPI header) on Leonardo, Due...

// #define USE_OLD_STYLE_WIRING

#ifdef USE_OLD_STYLE_WIRING

#define PIN_MOSI	16
#define PIN_MISO	14
#define PIN_SCK		15

#endif

// HOODLOADER2 means running sketches on the atmega16u2 
// serial converter chips on Uno or Mega boards.
// We must use pins that are broken out:
#else 

#define RESET     	4
#define LED_HB    	7
#define LED_ERR   	6
#define LED_PMODE 	5

#endif

// By default, use hardware SPI pins:
#ifndef PIN_MOSI
#define PIN_MOSI 	MOSI
#endif

#ifndef PIN_MISO
#define PIN_MISO 	MISO
#endif

#ifndef PIN_SCK
#define PIN_SCK 	SCK
#endif

// Force bitbanged SPI if not using the hardware SPI pins:
#if (PIN_MISO != MISO) ||  (PIN_MOSI != MOSI) || (PIN_SCK != SCK)
#undef USE_HARDWARE_SPI
#endif


// Configure the serial port to use.
//
// Prefer the USB virtual serial port (aka. native USB port), if the Arduino has one:
//   - it does not autoreset (except for the magic baud rate of 1200).
//   - it is more reliable because of USB handshaking.
//
// Leonardo and similar have an USB virtual serial port: 'Serial'.
// Due and Zero have an USB virtual serial port: 'SerialUSB'.
//
// On the Due and Zero, 'Serial' can be used too, provided you disable autoreset.
// To use 'Serial': #define SERIAL Serial

#ifdef SERIAL_PORT_USBVIRTUAL
#define SERIAL SERIAL_PORT_USBVIRTUAL
#else
#define SERIAL Serial
#endif


// Configure the baud rate:

// #define BAUDRATE	19200
#define BAUDRATE	115200
// #define BAUDRATE	1000000


#define HWVER 2
#define SWMAJ 1
#define SWMIN 18

// STK Definitions
#define STK_OK      0x10
#define STK_FAILED  0x11
#define STK_UNKNOWN 0x12
#define STK_INSYNC  0x14
#define STK_NOSYNC  0x15
#define CRC_EOP     0x20 //ok it is a space...

void pulse(int pin, int times);

#ifdef USE_HARDWARE_SPI
#include "SPI.h"
#else

#define SPI_MODE0 0x00

class SPISettings {
public:
  // clock is in Hz
  SPISettings(uint32_t clock, uint8_t bitOrder, uint8_t dataMode) : clock(clock){
    (void) bitOrder;
    (void) dataMode;
  };

private:
  uint32_t clock;

friend class BitBangedSPI;
};

class BitBangedSPI {
public:
  void begin() {
    digitalWrite(PIN_SCK, LOW);
    digitalWrite(PIN_MOSI, LOW);
    pinMode(PIN_SCK, OUTPUT);
    pinMode(PIN_MOSI, OUTPUT);
    pinMode(PIN_MISO, INPUT);
  }

  void beginTransaction(SPISettings settings) {
    pulseWidth = (500000 + settings.clock - 1) / settings.clock;
    if (pulseWidth == 0)
      pulseWidth = 1;
  }

  void end() {}

  uint8_t transfer (uint8_t b) {
    for (unsigned int i = 0; i < 8; ++i) {
      digitalWrite(PIN_MOSI, (b & 0x80) ? HIGH : LOW);
      digitalWrite(PIN_SCK, HIGH);
      delayMicroseconds(pulseWidth);
      b = (b << 1) | digitalRead(PIN_MISO);
      digitalWrite(PIN_SCK, LOW); // slow pulse
      delayMicroseconds(pulseWidth);
    }
    return b;
  }

private:
  unsigned long pulseWidth; // in microseconds
};

static BitBangedSPI SPI;

#endif

void setup() {
  SERIAL.begin(BAUDRATE);

  pinMode(LED_PMODE, OUTPUT);
  pulse(LED_PMODE, 2);
  pinMode(LED_ERR, OUTPUT);
  pulse(LED_ERR, 2);
  pinMode(LED_HB, OUTPUT);
  pulse(LED_HB, 2);

}

int error = 0;
int pmode = 0;
// address for reading and writing, set by 'U' command
unsigned int here;
uint8_t buff[256]; // global block storage

#define beget16(addr) (*addr * 256 + *(addr+1) )
typedef struct param {
  uint8_t devicecode;
  uint8_t revision;
  uint8_t progtype;
  uint8_t parmode;
  uint8_t polling;
  uint8_t selftimed;
  uint8_t lockbytes;
  uint8_t fusebytes;
  uint8_t flashpoll;
  uint16_t eeprompoll;
  uint16_t pagesize;
  uint16_t eepromsize;
  uint32_t flashsize;
}
parameter;

parameter param;

// this provides a heartbeat on pin 9, so you can tell the software is running.
uint8_t hbval = 128;
int8_t hbdelta = 8;
void heartbeat() {
  static unsigned long last_time = 0;
  unsigned long now = millis();
  if ((now - last_time) < 40)
    return;
  last_time = now;
  if (hbval > 192) hbdelta = -hbdelta;
  if (hbval < 32) hbdelta = -hbdelta;
  hbval += hbdelta;
  analogWrite(LED_HB, hbval);
}

static bool rst_active_high;

void reset_target(bool reset) {
  digitalWrite(RESET, ((reset && rst_active_high) || (!reset && !rst_active_high)) ? HIGH : LOW);
}

void loop(void) {
  // is pmode active?
  if (pmode) {
    digitalWrite(LED_PMODE, HIGH);
  } else {
    digitalWrite(LED_PMODE, LOW);
  }
  // is there an error?
  if (error) {
    digitalWrite(LED_ERR, HIGH);
  } else {
    digitalWrite(LED_ERR, LOW);
  }

  // light the heartbeat LED
  heartbeat();
  if (SERIAL.available()) {
    avrisp();
  }
}

uint8_t getch() {
  while (!SERIAL.available());
  return SERIAL.read();
}
void fill(int n) {
  for (int x = 0; x < n; x++) {
    buff[x] = getch();
  }
}

#define PTIME 30
void pulse(int pin, int times) {
  do {
    digitalWrite(pin, HIGH);
    delay(PTIME);
    digitalWrite(pin, LOW);
    delay(PTIME);
  } while (times--);
}

void prog_lamp(int state) {
  if (PROG_FLICKER) {
    digitalWrite(LED_PMODE, state);
  }
}

uint8_t spi_transaction(uint8_t a, uint8_t b, uint8_t c, uint8_t d) {
  SPI.transfer(a);
  SPI.transfer(b);
  SPI.transfer(c);
  return SPI.transfer(d);
}

void empty_reply() {
  if (CRC_EOP == getch()) {
    SERIAL.print((char)STK_INSYNC);
    SERIAL.print((char)STK_OK);
  } else {
    error++;
    SERIAL.print((char)STK_NOSYNC);
  }
}

void breply(uint8_t b) {
  if (CRC_EOP == getch()) {
    SERIAL.print((char)STK_INSYNC);
    SERIAL.print((char)b);
    SERIAL.print((char)STK_OK);
  } else {
    error++;
    SERIAL.print((char)STK_NOSYNC);
  }
}

void get_version(uint8_t c) {
  switch (c) {
    case 0x80:
      breply(HWVER);
      break;
    case 0x81:
      breply(SWMAJ);
      break;
    case 0x82:
      breply(SWMIN);
      break;
    case 0x93:
      breply('S'); // serial programmer
      break;
    default:
      breply(0);
  }
}

void set_parameters() {
  // call this after reading paramter packet into buff[]
  param.devicecode = buff[0];
  param.revision   = buff[1];
  param.progtype   = buff[2];
  param.parmode    = buff[3];
  param.polling    = buff[4];
  param.selftimed  = buff[5];
  param.lockbytes  = buff[6];
  param.fusebytes  = buff[7];
  param.flashpoll  = buff[8];
  // ignore buff[9] (= buff[8])
  // following are 16 bits (big endian)
  param.eeprompoll = beget16(&buff[10]);
  param.pagesize   = beget16(&buff[12]);
  param.eepromsize = beget16(&buff[14]);

  // 32 bits flashsize (big endian)
  param.flashsize = buff[16] * 0x01000000
                    + buff[17] * 0x00010000
                    + buff[18] * 0x00000100
                    + buff[19];

  // avr devices have active low reset, at89sx are active high
  rst_active_high = (param.devicecode >= 0xe0);
}

void start_pmode() {

  // Reset target before driving PIN_SCK or PIN_MOSI

  // SPI.begin() will configure SS as output,
  // so SPI master mode is selected.
  // We have defined RESET as pin 10,
  // which for many arduino's is not the SS pin.
  // So we have to configure RESET as output here,
  // (reset_target() first sets the correct level)
  reset_target(true);
  pinMode(RESET, OUTPUT);
  SPI.begin();
  SPI.beginTransaction(SPISettings(SPI_CLOCK, MSBFIRST, SPI_MODE0));

  // See avr datasheets, chapter "SERIAL_PRG Programming Algorithm":

  // Pulse RESET after PIN_SCK is low:
  digitalWrite(PIN_SCK, LOW);
  delay(20); // discharge PIN_SCK, value arbitrally chosen
  reset_target(false);
  // Pulse must be minimum 2 target CPU clock cycles
  // so 100 usec is ok for CPU speeds above 20KHz
  delayMicroseconds(100);
  reset_target(true);

  // Send the enable programming command:
  delay(50); // datasheet: must be > 20 msec
  spi_transaction(0xAC, 0x53, 0x00, 0x00);
  pmode = 1;
}

void end_pmode() {
  SPI.end();
  // We're about to take the target out of reset
  // so configure SPI pins as input
  pinMode(PIN_MOSI, INPUT);
  pinMode(PIN_SCK, INPUT);
  reset_target(false);
  pinMode(RESET, INPUT);
  pmode = 0;
}

void universal() {
  uint8_t ch;

  fill(4);
  ch = spi_transaction(buff[0], buff[1], buff[2], buff[3]);
  breply(ch);
}

void flash(uint8_t hilo, unsigned int addr, uint8_t data) {
  spi_transaction(0x40 + 8 * hilo,
                  addr >> 8 & 0xFF,
                  addr & 0xFF,
                  data);
}
void commit(unsigned int addr) {
  if (PROG_FLICKER) {
    prog_lamp(LOW);
  }
  spi_transaction(0x4C, (addr >> 8) & 0xFF, addr & 0xFF, 0);
  if (PROG_FLICKER) {
    delay(PTIME);
    prog_lamp(HIGH);
  }
}

unsigned int current_page() {
  if (param.pagesize == 32) {
    return here & 0xFFFFFFF0;
  }
  if (param.pagesize == 64) {
    return here & 0xFFFFFFE0;
  }
  if (param.pagesize == 128) {
    return here & 0xFFFFFFC0;
  }
  if (param.pagesize == 256) {
    return here & 0xFFFFFF80;
  }
  return here;
}


void write_flash(int length) {
  fill(length);
  if (CRC_EOP == getch()) {
    SERIAL.print((char) STK_INSYNC);
    SERIAL.print((char) write_flash_pages(length));
  } else {
    error++;
    SERIAL.print((char) STK_NOSYNC);
  }
}

uint8_t write_flash_pages(int length) {
  int x = 0;
  unsigned int page = current_page();
  while (x < length) {
    if (page != current_page()) {
      commit(page);
      page = current_page();
    }
    flash(LOW, here, buff[x++]);
    flash(HIGH, here, buff[x++]);
    here++;
  }

  commit(page);

  return STK_OK;
}

#define EECHUNK (32)
uint8_t write_eeprom(unsigned int length) {
  // here is a word address, get the byte address
  unsigned int start = here * 2;
  unsigned int remaining = length;
  if (length > param.eepromsize) {
    error++;
    return STK_FAILED;
  }
  while (remaining > EECHUNK) {
    write_eeprom_chunk(start, EECHUNK);
    start += EECHUNK;
    remaining -= EECHUNK;
  }
  write_eeprom_chunk(start, remaining);
  return STK_OK;
}
// write (length) bytes, (start) is a byte address
uint8_t write_eeprom_chunk(unsigned int start, unsigned int length) {
  // this writes byte-by-byte,
  // page writing may be faster (4 bytes at a time)
  fill(length);
  prog_lamp(LOW);
  for (unsigned int x = 0; x < length; x++) {
    unsigned int addr = start + x;
    spi_transaction(0xC0, (addr >> 8) & 0xFF, addr & 0xFF, buff[x]);
    delay(45);
  }
  prog_lamp(HIGH);
  return STK_OK;
}

void program_page() {
  char result = (char) STK_FAILED;
  unsigned int length = 256 * getch();
  length += getch();
  char memtype = getch();
  // flash memory @here, (length) bytes
  if (memtype == 'F') {
    write_flash(length);
    return;
  }
  if (memtype == 'E') {
    result = (char)write_eeprom(length);
    if (CRC_EOP == getch()) {
      SERIAL.print((char) STK_INSYNC);
      SERIAL.print(result);
    } else {
      error++;
      SERIAL.print((char) STK_NOSYNC);
    }
    return;
  }
  SERIAL.print((char)STK_FAILED);
  return;
}

uint8_t flash_read(uint8_t hilo, unsigned int addr) {
  return spi_transaction(0x20 + hilo * 8,
                         (addr >> 8) & 0xFF,
                         addr & 0xFF,
                         0);
}

char flash_read_page(int length) {
  for (int x = 0; x < length; x += 2) {
    uint8_t low = flash_read(LOW, here);
    SERIAL.print((char) low);
    uint8_t high = flash_read(HIGH, here);
    SERIAL.print((char) high);
    here++;
  }
  return STK_OK;
}

char eeprom_read_page(int length) {
  // here again we have a word address
  int start = here * 2;
  for (int x = 0; x < length; x++) {
    int addr = start + x;
    uint8_t ee = spi_transaction(0xA0, (addr >> 8) & 0xFF, addr & 0xFF, 0xFF);
    SERIAL.print((char) ee);
  }
  return STK_OK;
}

void read_page() {
  char result = (char)STK_FAILED;
  int length = 256 * getch();
  length += getch();
  char memtype = getch();
  if (CRC_EOP != getch()) {
    error++;
    SERIAL.print((char) STK_NOSYNC);
    return;
  }
  SERIAL.print((char) STK_INSYNC);
  if (memtype == 'F') result = flash_read_page(length);
  if (memtype == 'E') result = eeprom_read_page(length);
  SERIAL.print(result);
}

void read_signature() {
  if (CRC_EOP != getch()) {
    error++;
    SERIAL.print((char) STK_NOSYNC);
    return;
  }
  SERIAL.print((char) STK_INSYNC);
  uint8_t high = spi_transaction(0x30, 0x00, 0x00, 0x00);
  SERIAL.print((char) high);
  uint8_t middle = spi_transaction(0x30, 0x00, 0x01, 0x00);
  SERIAL.print((char) middle);
  uint8_t low = spi_transaction(0x30, 0x00, 0x02, 0x00);
  SERIAL.print((char) low);
  SERIAL.print((char) STK_OK);
}
//////////////////////////////////////////
//////////////////////////////////////////


////////////////////////////////////
////////////////////////////////////
void avrisp() {
  uint8_t ch = getch();
  switch (ch) {
    case '0': // signon
      error = 0;
      empty_reply();
      break;
    case '1':
      if (getch() == CRC_EOP) {
        SERIAL.print((char) STK_INSYNC);
        SERIAL.print("AVR ISP");
        SERIAL.print((char) STK_OK);
      }
      else {
        error++;
        SERIAL.print((char) STK_NOSYNC);
      }
      break;
    case 'A':
      get_version(getch());
      break;
    case 'B':
      fill(20);
      set_parameters();
      empty_reply();
      break;
    case 'E': // extended parameters - ignore for now
      fill(5);
      empty_reply();
      break;
    case 'P':
      if (!pmode)
        start_pmode();
      empty_reply();
      break;
    case 'U': // set address (word)
      here = getch();
      here += 256 * getch();
      empty_reply();
      break;

    case 0x60: //STK_PROG_FLASH
      getch(); // low addr
      getch(); // high addr
      empty_reply();
      break;
    case 0x61: //STK_PROG_DATA
      getch(); // data
      empty_reply();
      break;

    case 0x64: //STK_PROG_PAGE
      program_page();
      break;

    case 0x74: //STK_READ_PAGE 't'
      read_page();
      break;

    case 'V': //0x56
      universal();
      break;
    case 'Q': //0x51
      error = 0;
      end_pmode();
      empty_reply();
      break;

    case 0x75: //STK_READ_SIGN 'u'
      read_signature();
      break;

    // expecting a command, not CRC_EOP
    // this is how we can get back in sync
    case CRC_EOP:
      error++;
      SERIAL.print((char) STK_NOSYNC);
      break;

    // anything else we will return STK_UNKNOWN
    default:
      error++;
      if (CRC_EOP == getch())
        SERIAL.print((char)STK_UNKNOWN);
      else
        SERIAL.print((char)STK_NOSYNC);
  }
}

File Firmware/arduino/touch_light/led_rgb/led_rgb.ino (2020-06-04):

/*
  ledcWrite_RGB.ino
  Runs through the full 255 color spectrum for an rgb led 
  Demonstrate ledcWrite functionality for driving leds with PWM on ESP32
 
  This example code is in the public domain.
  
  Some basic modifications were made by vseven, mostly commenting.
 */
 
// Set up the rgb led names
uint8_t ledR = 17;
uint8_t ledG = 18;
uint8_t ledB = 19; 

uint8_t ledArray[3] = {1, 2, 3}; // three led channels

const boolean invert = false; // set true if common anode, false if common cathode

uint8_t color = 0;          // a value from 0 to 255 representing the hue
uint32_t R, G, B;           // the Red Green and Blue color components
uint8_t brightness = 255;  // 255 is maximum brightness, but can be changed.  Might need 256 for common anode to fully turn off.

// the setup routine runs once when you press reset:
void setup() 
{            
  Serial.begin(115200);
  delay(10); 
  
  ledcAttachPin(ledR, 1); // assign RGB led pins to channels
  ledcAttachPin(ledG, 2);
  ledcAttachPin(ledB, 3);
  
  // Initialize channels 
  // channels 0-15, resolution 1-16 bits, freq limits depend on resolution
  // ledcSetup(uint8_t channel, uint32_t freq, uint8_t resolution_bits);
  ledcSetup(1, 12000, 8); // 12 kHz PWM, 8-bit resolution
  ledcSetup(2, 12000, 8);
  ledcSetup(3, 12000, 8);
}

// void loop runs over and over again
void loop() 
{
  Serial.println("Send all LEDs a 255 and wait 2 seconds.");
  // If your RGB LED turns off instead of on here you should check if the LED is common anode or cathode.
  // If it doesn't fully turn off and is common anode try using 256.
  ledcWrite(1, 255);
  ledcWrite(2, 255);
  ledcWrite(3, 255);
  delay(2000);
  Serial.println("Send all LEDs a 0 and wait 2 seconds.");
  ledcWrite(1, 0);
  ledcWrite(2, 0);
  ledcWrite(3, 0);
  delay(2000);
 
  Serial.println("Starting color fade loop.");
  
 for (color = 0; color < 255; color++) { // Slew through the color spectrum

  hueToRGB(color, brightness);  // call function to convert hue to RGB

  // write the RGB values to the pins
  ledcWrite(1, R); // write red component to channel 1, etc.
  ledcWrite(2, G);   
  ledcWrite(3, B); 
 
  delay(100); // full cycle of rgb over 256 colors takes 26 seconds
 }
 
}

// Courtesy http://www.instructables.com/id/How-to-Use-an-RGB-LED/?ALLSTEPS
// function to convert a color to its Red, Green, and Blue components.

void hueToRGB(uint8_t hue, uint8_t brightness)
{
    uint16_t scaledHue = (hue * 6);
    uint8_t segment = scaledHue / 256; // segment 0 to 5 around the
                                            // color wheel
    uint16_t segmentOffset =
      scaledHue - (segment * 256); // position within the segment

    uint8_t complement = 0;
    uint16_t prev = (brightness * ( 255 -  segmentOffset)) / 256;
    uint16_t next = (brightness *  segmentOffset) / 256;

    if(invert)
    {
      brightness = 255 - brightness;
      complement = 255;
      prev = 255 - prev;
      next = 255 - next;
    }

    switch(segment ) {
    case 0:      // red
        R = brightness;
        G = next;
        B = complement;
    break;
    case 1:     // yellow
        R = prev;
        G = brightness;
        B = complement;
    break;
    case 2:     // green
        R = complement;
        G = brightness;
        B = next;
    break;
    case 3:    // cyan
        R = complement;
        G = prev;
        B = brightness;
    break;
    case 4:    // blue
        R = next;
        G = complement;
        B = brightness;
    break;
   case 5:      // magenta
    default:
        R = brightness;
        G = complement;
        B = prev;
    break;
    }
}

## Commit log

2018-07-27 Added LPC11C22 library an initial schematic
    [domenode.kicad_pcb, domenode.sch]
2018-07-28 Moving to ESP32 and CAN transceiver idea
    [ESP32-Footprints.kicad_pcb, ESP32-Footprints.sch, domenode.sch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]
2018-07-28 Added SN65HVD230 CAN transceiver library (no pin assignments yet).
    [domenode.sch]
2018-07-28 Adding LED stuff. Also upgrading to KiCad 5.0
    [domenode.sch]
2018-07-28 Upgraded to KiCad 5.0 and did symbol update. Added 5 Neopixels.
    [domenode-2018-07-28-17-01-30.sch]
2018-07-28 Need decoupling caps on pixels
    [domenode.sch]
2018-07-28 Added RGB 'shield' header for a more powerful RGB led. PIxels still need caps :)
    [domenode.sch]
2018-07-29 Pixels have caps. Added external connectors.
    [domenode.sch]
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2018-07-29 Um, tons of changes. Added:
    - Dev board footprint
    - Power regulators and selectors
    - Other things.
    [domenode.sch]
2018-07-29 Tidied up a bit
    [domenode.sch]
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2018-07-29 More tinkering. Added required on board switches and moved some pins around.
    [domenode.sch]
2018-07-29 Added pullups
    [domenode.sch]
2018-07-29 Added IR Tx/Rx
    [domenode.sch]
2018-07-29 Fixed some pin assignments
    [domenode.sch]
2018-07-29 Added simple transistor-powered speaker circuit
    [domenode.sch]
2018-07-30 Fixed symbol issues. Need to add kicad .lib files to Git repo
    [domenode.sch]
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2018-07-30 Updated board with new buck regulator
    [domenode.sch]
2018-07-30 Fixed a couple of mistakes
    [domenode.sch]
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2018-07-30 Fixed CAN bus transceiver circuit. Tidied.
    [domenode.sch]
2018-07-30 Added simple schematic for distribution board
    [distboard.kicad_pcb, distboard.sch]
2018-07-30 Playing with dist board PCB
    [distboard.kicad_pcb, distboard.sch]
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2018-07-31 Added MAX4466 microphone breakout header
    [domenode.sch]
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2018-07-31 Added capacitive touch ring mounting pads
    [domenode.sch]
2018-07-31 Added ground mount points (for shield or whatever)
    [domenode.sch]
2018-07-31 Started assigning footprints and started PCB
    [domenode.kicad_pcb, domenode.sch]
2018-08-01 More footprint assigns. More PCB design.
    [_saved_domenode.sch, domenode.kicad_pcb]
2018-08-01 Bit more layout :)
    [domenode.kicad_pcb, domenode.sch]
2018-08-01 Populated board and footprints.
    [WS2812_RGB_LED_updated.stp, _saved_domenode.sch, domenode.kicad_pcb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]
2018-08-01 Removed dev board footprint and associated components. No space!
    [domenode.sch]
2018-08-01 Added CAN termination header
    [domenode.sch]
2018-08-01 Researched C3 - needs to be tantalum, recommended Pad B size.
    [domenode.sch]
2018-08-02 Added SHM label somewhere on the PCB
    [domenode.kicad_pcb]
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2018-08-02 Moved pins around for ESP32 compatibility
    [domenode.sch]
2018-08-02 Made board 5mm bigger, Moved ESP32 to back of board
    [domenode.kicad_pcb, domenode.sch]
2018-08-02 Added generic RJ45 connector footprint.
    [domenode.kicad_pcb]
2018-08-02 Added 3D RJ45 model
    [domenode.kicad_pcb, wurth_615008143721 (rev1).stp]
2018-08-02 Added cap for D9
    [domenode.kicad_pcb, domenode.sch]
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2018-08-02 More wiring and layout
    [_saved_domenode.sch, domenode.kicad_pcb, domenode.sch]
2018-08-02 Changed pins for RLDR and FLDR to ADC1. ADC2 not implemented
    [domenode.sch]
2018-08-03 moved some stuff around and it's looking potentially better
    [domenode.kicad_pcb, domenode.sch]
2018-08-03 More PCB work. Added footprint for IR transistor (MMBT2222A)
    [domenode.kicad_pcb, domenode.sch]
2018-08-03 wired up CAN L and H
    [domenode.kicad_pcb]
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2018-08-03 Fixed capacitive pads and traced them out
    [domenode.kicad_pcb, domenode.sch]
2018-08-03 Added moar decoupling caps and laid out in PCB
    [domenode.kicad_pcb, domenode.sch]
2018-08-03 Updated buck regulator footprint to make it easier to solder
    [domenode.kicad_pcb]
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2018-08-03 Changed J16 header to GND. Don't need two sets of power RGB GPIOs
    [domenode.sch]
2018-08-05 Added 5v rail to rgb header
    [domenode.kicad_pcb, domenode.sch]
2018-08-05 First clean DRC done.
    [domenode.kicad_pcb]
2018-08-05 Added ground vias for bald patches. Second clean DRC
    [domenode.kicad_pcb]
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2018-08-06 Undone neopixel mess up
    [domenode.kicad_pcb]
2018-08-06 Fixing DRC checks in schematic
    [domenode.sch]
2018-08-06 Added power flag to fix DRC errors for CANV input
    [domenode.sch]
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2018-08-06 More wiring. Passes DRC
    [domenode.kicad_pcb]
2018-08-06 Added more grounding vias
    [domenode.kicad_pcb]
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2018-08-06 Added 'backup' footprint for RJ45 shield
    [domenode.kicad_pcb]
2018-08-06 Fixed CANL and CANH traces
    [domenode.kicad_pcb]
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2018-08-06 more minor changes. Added some 'thermal' vias to underside of neopixels
    [domenode.kicad_pcb]
2018-08-06 Track cleanup. DRC check clean.
    [domenode.kicad_pcb]
2018-08-08 Final DRC. Plotted gerbers, ordered v0.1b boards
    [domenode-B.Cu.gbr, domenode-B.Mask.gbr, domenode-B.Paste.gbr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]
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2018-08-13 Finalised node board v0.1b
    [domenode-B.Cu.gbl, domenode-B.Cu.gbr, domenode-B.Mask.gbr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]
2018-08-13 Working on dist board
    [distboard.kicad_pcb, distboard.sch]
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2018-08-13 Gerbers for v0.1b distboard
    [distboard-B.Cu.gbl, distboard-B.Mask.gbs, distboard-B.Paste.gbp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]
2018-08-23 Added debug mode to hold at reboots, more EEPROM code
    [NodeWare.ino]
2018-08-24 Replaced EEPROM storage with non-volatile storage, added a method to set node ID
    [NodeWare.ino]
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2018-08-25 Created spreadsheet for planning node IDs and function codes
    [CAN IDs and Codes.ods]
2018-08-25 Embedded fonts in spreadsheet
    [CAN IDs and Codes.ods]
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2018-08-26 Added touch capability and started on CAN messages
    [CAN IDs and Codes.ods]
2018-08-27 Added heartbeat LED, Arduino OTA, tidied up code a little
    [CAN IDs and Codes.ods]
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
